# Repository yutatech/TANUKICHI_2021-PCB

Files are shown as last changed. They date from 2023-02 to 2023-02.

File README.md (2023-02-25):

# TANUKICHI_2021-PCB
This PCB is developed for RoboCup Junior Soccer. The robot has competed as "CAIO Tezukayama" in 2019 and "Leopard" in 2021.

## Related Web sites
- [Yuta's Blog](http://yuta.techblog.jp)
- [ Yuta - YouTube Channel](https://www.youtube.com/@yuta9428)
- [ Yuta@ciao_yuta - Twitter](https://twitter.com/ciao_yuta)

## Related Repositories
- [yutatech/RoboCup2021](https://github.com/yutatech/RoboCup2021)
- [yutatech/TANUKICHI_2021-Software](https://github.com/yutatech/TANUKICHI_2021-Software)

## Related Resources
#### TDP
- [Leopard RoboCup 2021 Team Discription Paper](http://yuta.techblog.jp/RoboCupJapanTournament2021/Leopard%20RoboCup%202021%20Team%20Discription%20Paper.pdf)

#### Video
- [Video - Leopard (Soccer Open) - RoboCup 2021 WORLDWIDE](https://www.youtube.com/watch?v=Lgoi_pQrCUY)
	- [This video](https://www.youtube.com/watch?v=PFkYVE7N84A) and [this video](https://www.youtube.com/watch?v=1l03lD6fXiQ) are also the same. Uploaded from TokyoTech.

## Awards
- ロボカップジュニア日本大会2021オンライン (RoboCup Junior Japan Tournament 2021 Online)
	- サッカーオープン 優勝 (SoccerOpen 1st Place)
	- ベストプレゼンビデオ賞 (Best Presentation Video Award)
	- ベストインタビュー賞 (Best Interview Award)
	- ベストビジュアルポスター賞 (Best Visual Poster Award)
- RoboCup 2021 WORLDWIDE
	- SoccerOpen Indvidual 1st Place
	- SoccerOpen SuperTeam 1st Place

## Environment
These files are edited with KiCAD 5.1.5

## PCB design files
- MAIN
	- This PCB is the main board of the robot. 
- MOTOR
	- This PCB drives 4 motors and 2 kickers. It is connected to MAIN with pin headers.
- LINE
	- This PCB includes 2 types of line sensor boards. The robot has two sensor boards of each type.
- TOP
	- This PCB distributes the wiring from MAIN to the devices mounted on top of the robot.
- BOTTOM
	- This PCB is connected to the line sensor board without using cables.
- BOOST V1
	- This PCB is a boost circuit for kickers. It outputs 60V. This version is installed to the robot because it is stable and works well.
- BOOST V2
	- This PCB is also a boost circuit for kickers. It outputs 150V. This version is an improvement on V1, but was not adopted because it would have caused noise in the surrounding circuit.
- ENCODER
	- This PCB is a magnetic pulse encoder board.
- PROTECTION
	- This PCB is Li-PO Battery protection circuit. The voltage of each cell is not monitored, so any imitation should be done at your own risk.

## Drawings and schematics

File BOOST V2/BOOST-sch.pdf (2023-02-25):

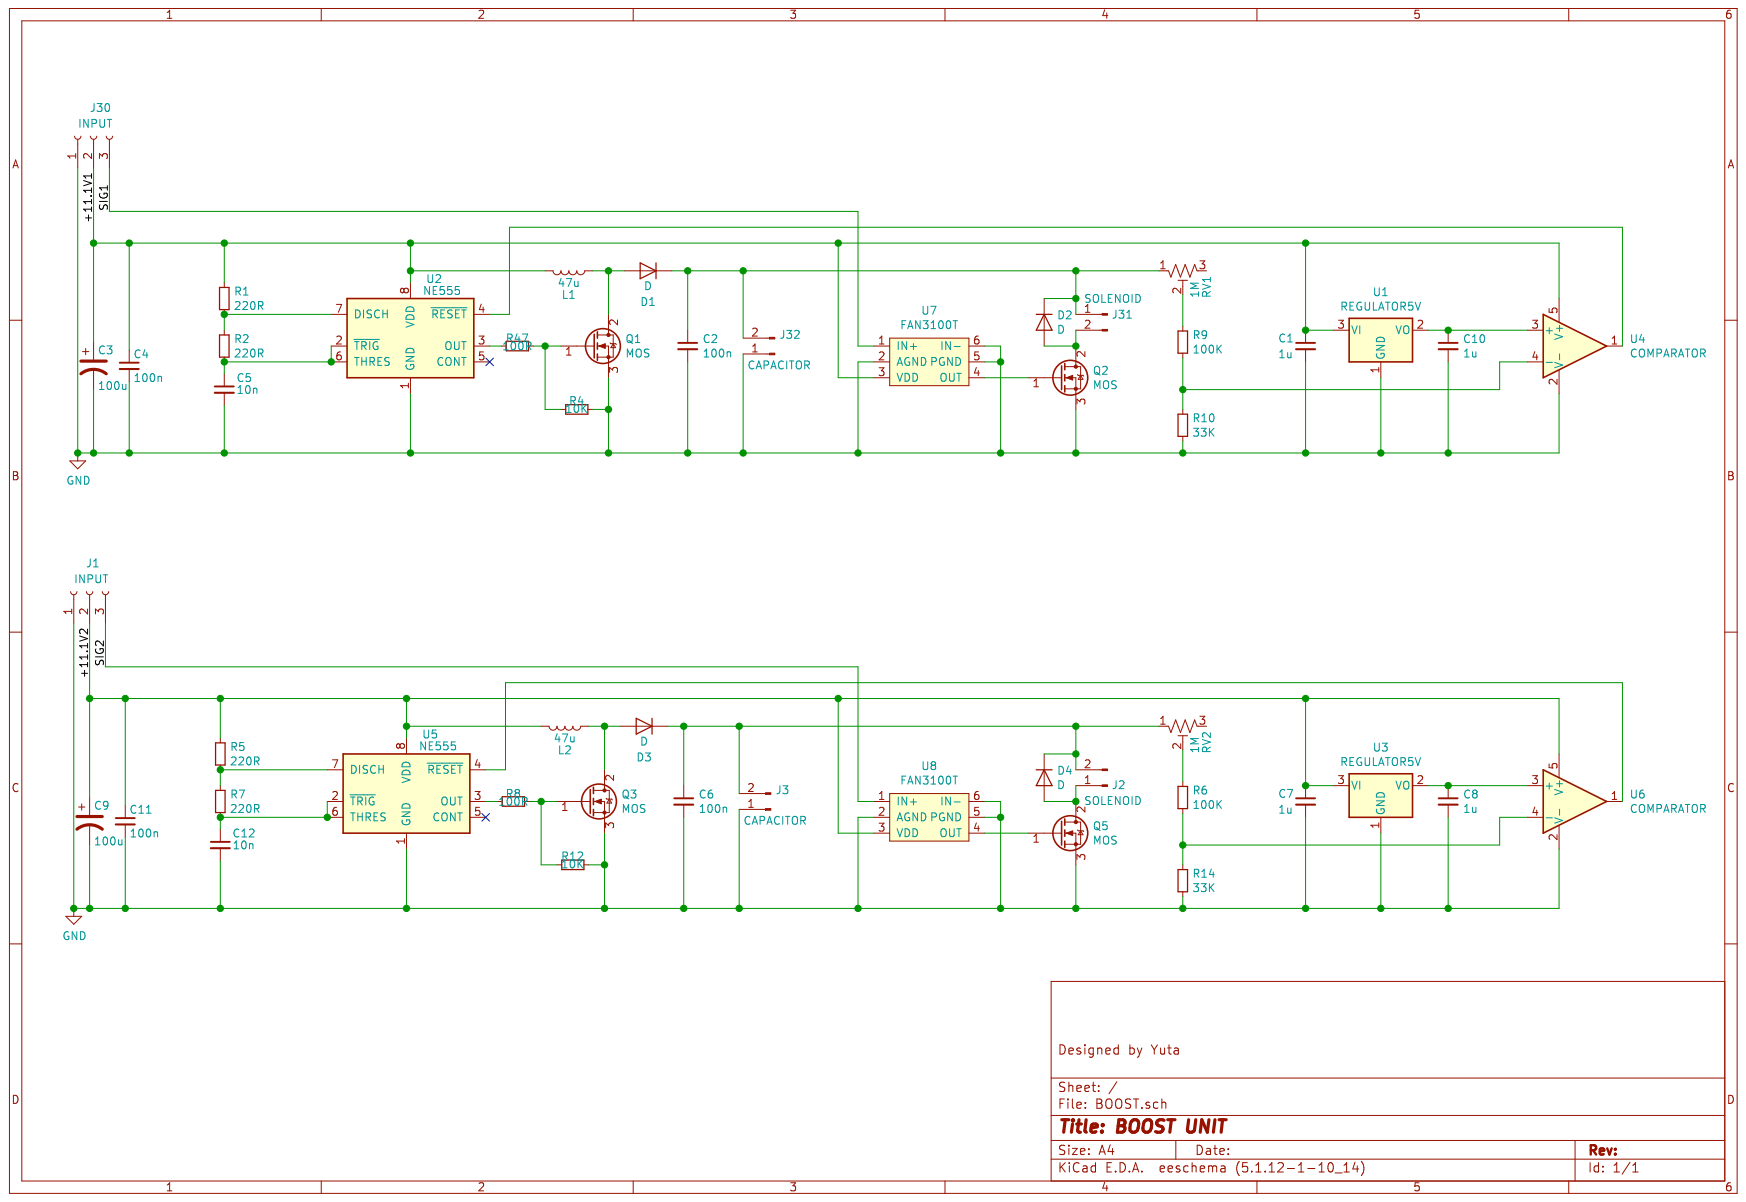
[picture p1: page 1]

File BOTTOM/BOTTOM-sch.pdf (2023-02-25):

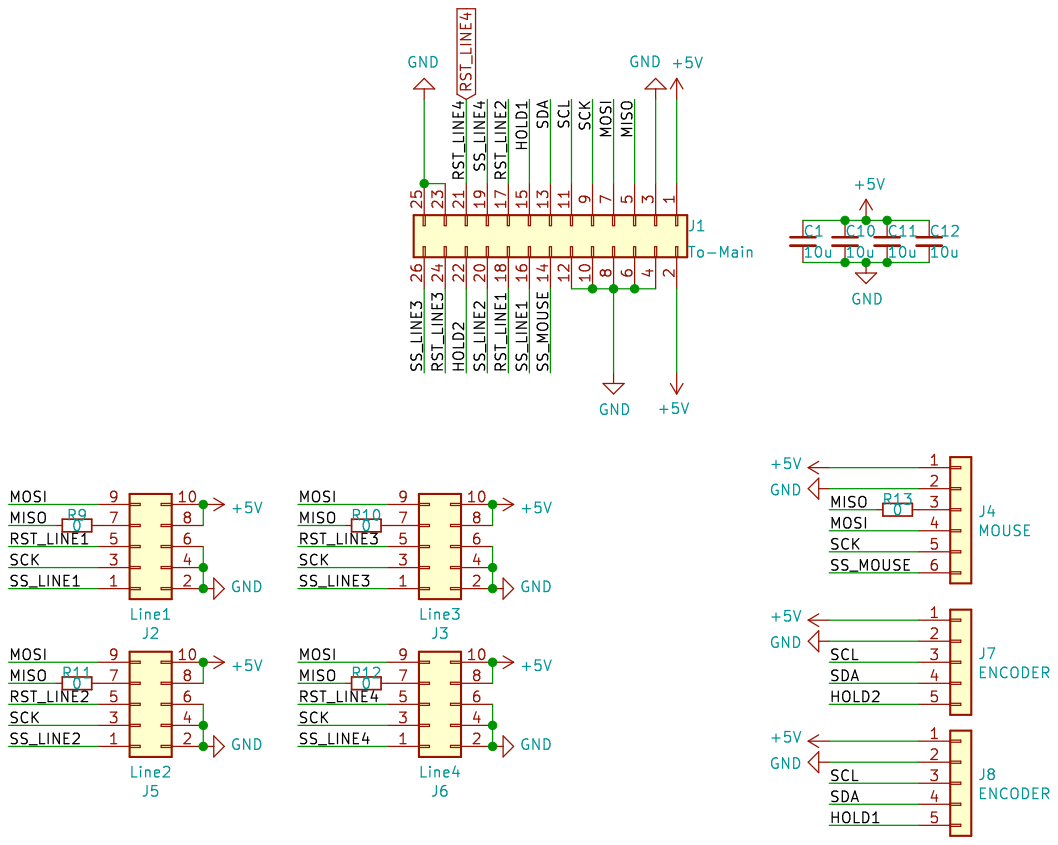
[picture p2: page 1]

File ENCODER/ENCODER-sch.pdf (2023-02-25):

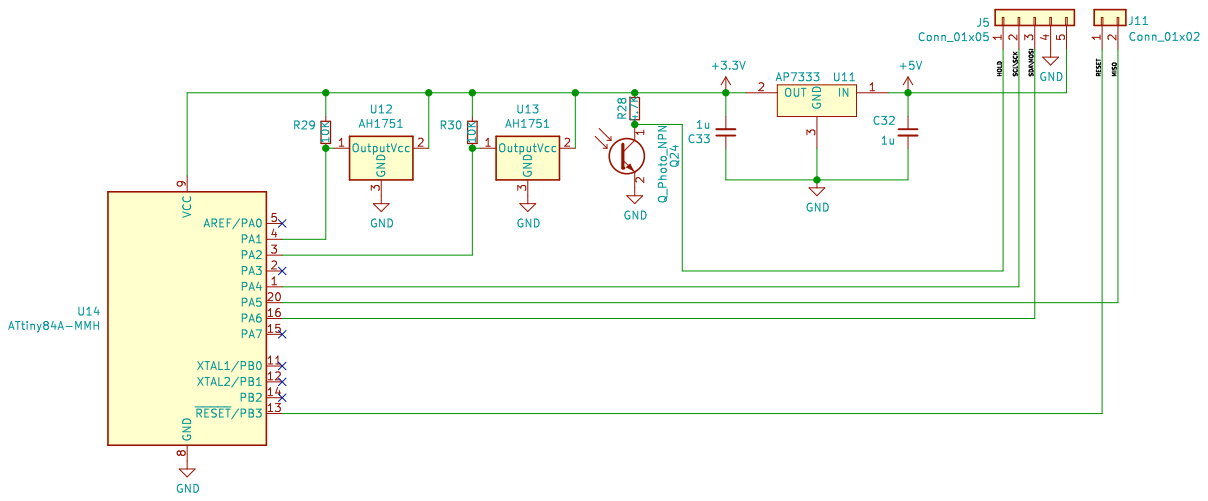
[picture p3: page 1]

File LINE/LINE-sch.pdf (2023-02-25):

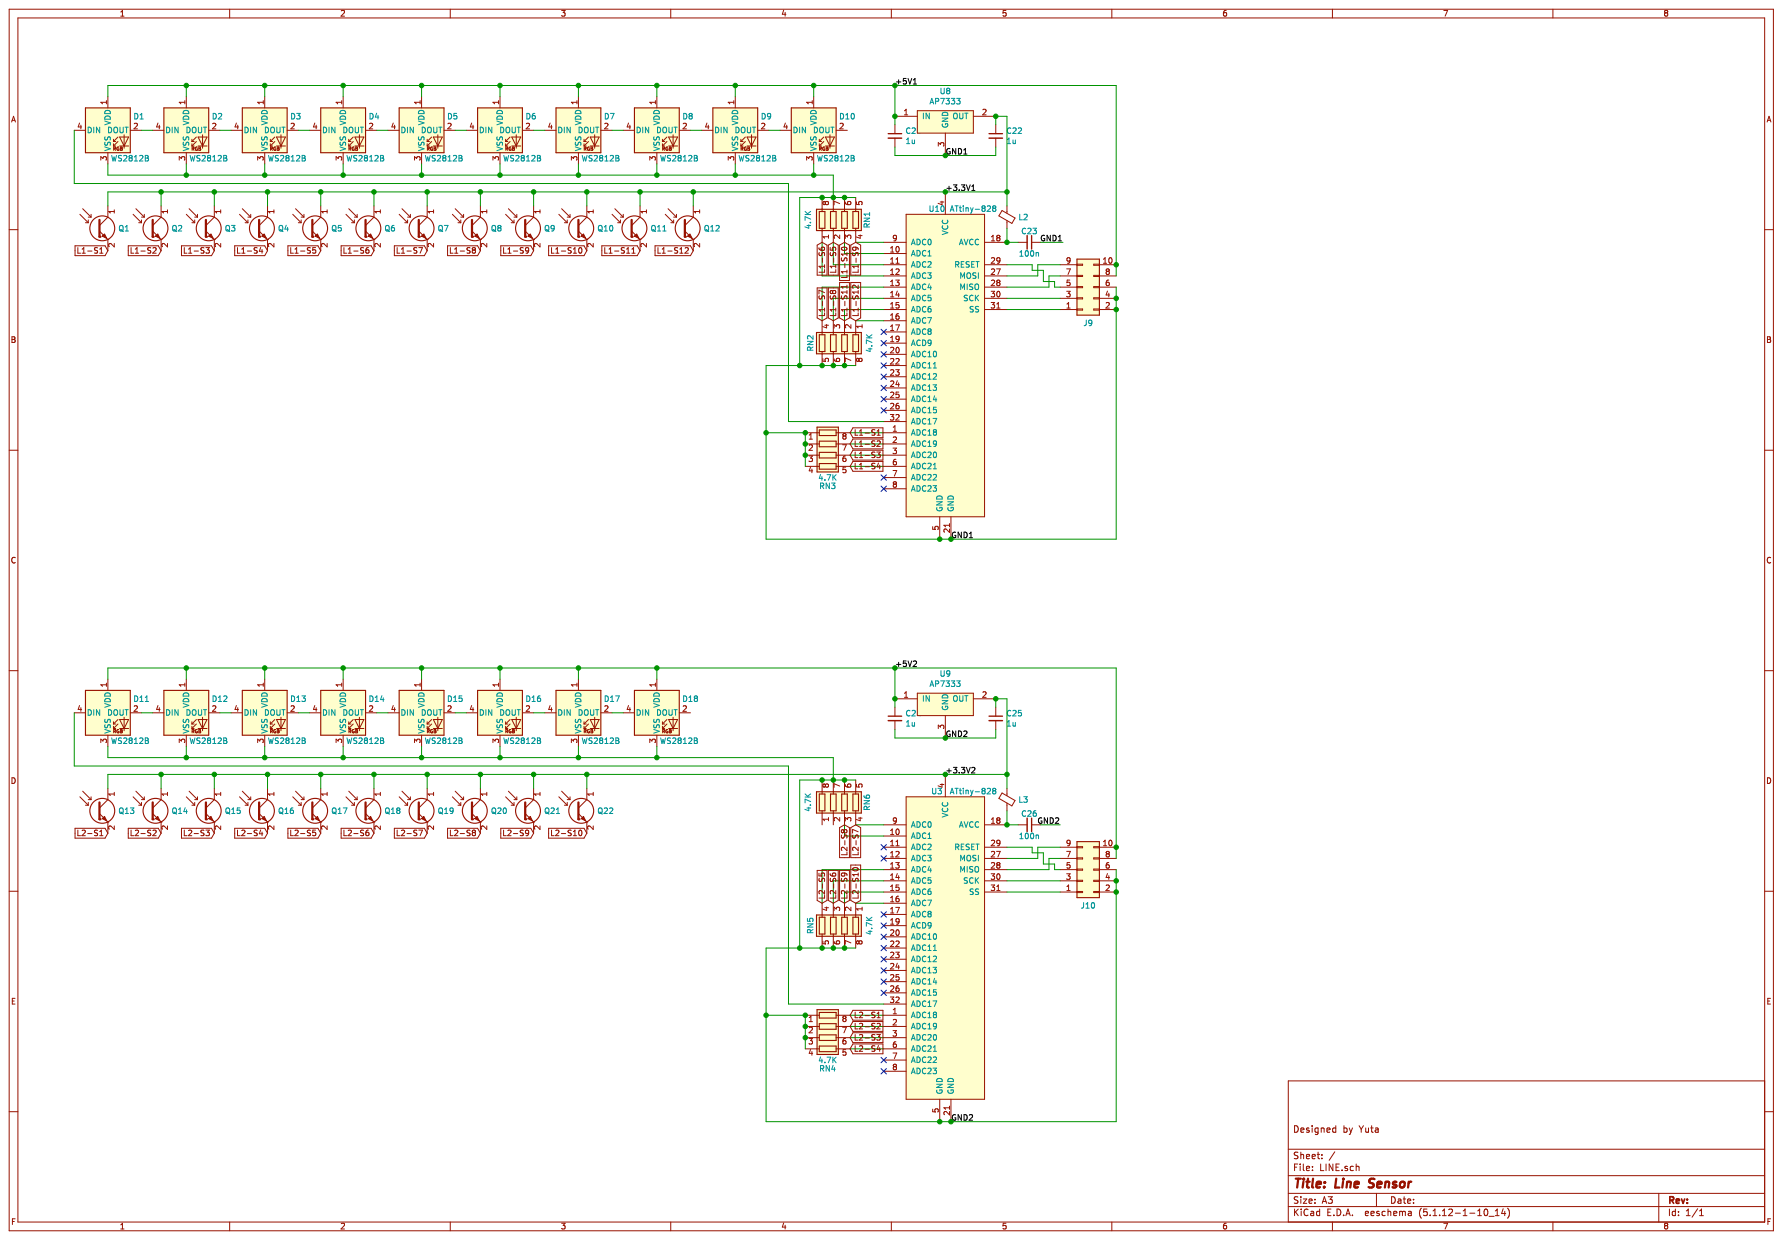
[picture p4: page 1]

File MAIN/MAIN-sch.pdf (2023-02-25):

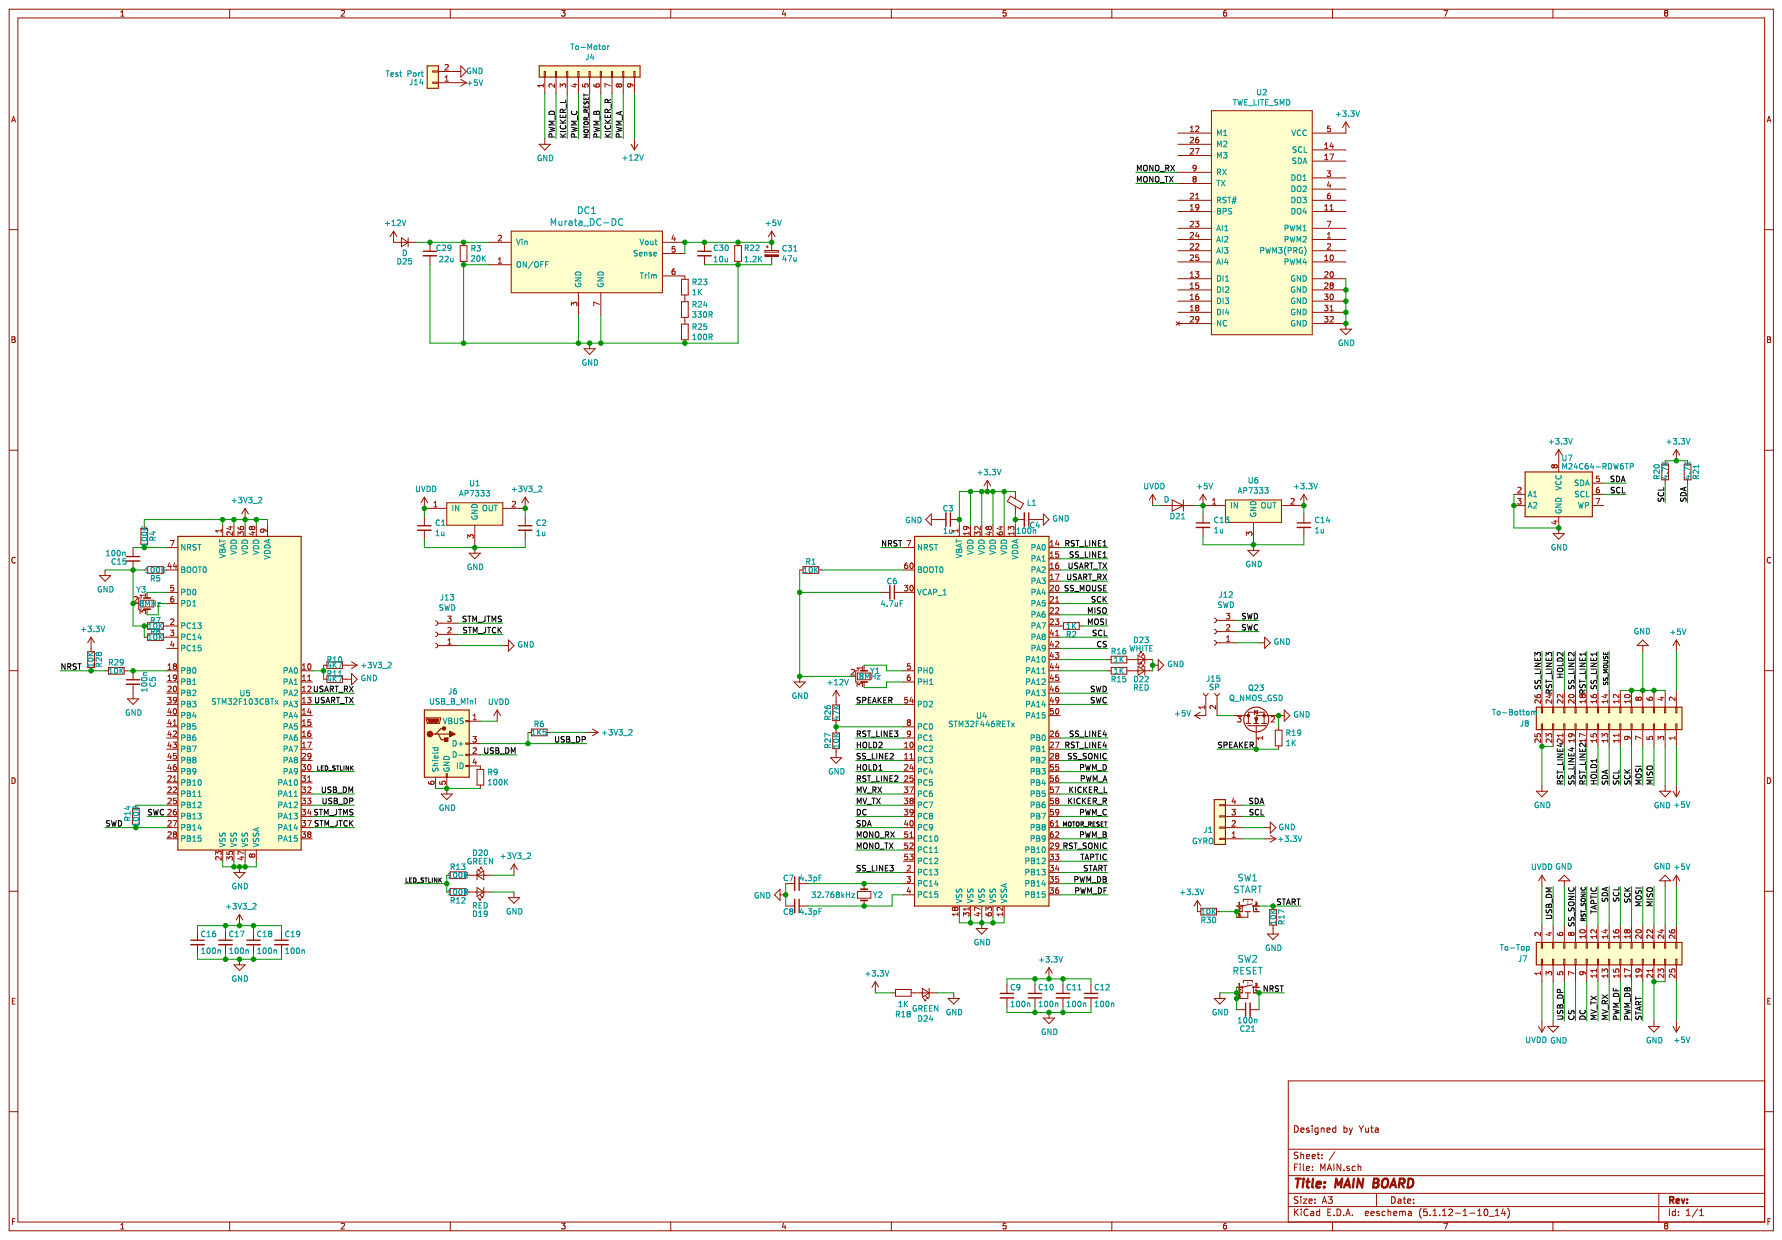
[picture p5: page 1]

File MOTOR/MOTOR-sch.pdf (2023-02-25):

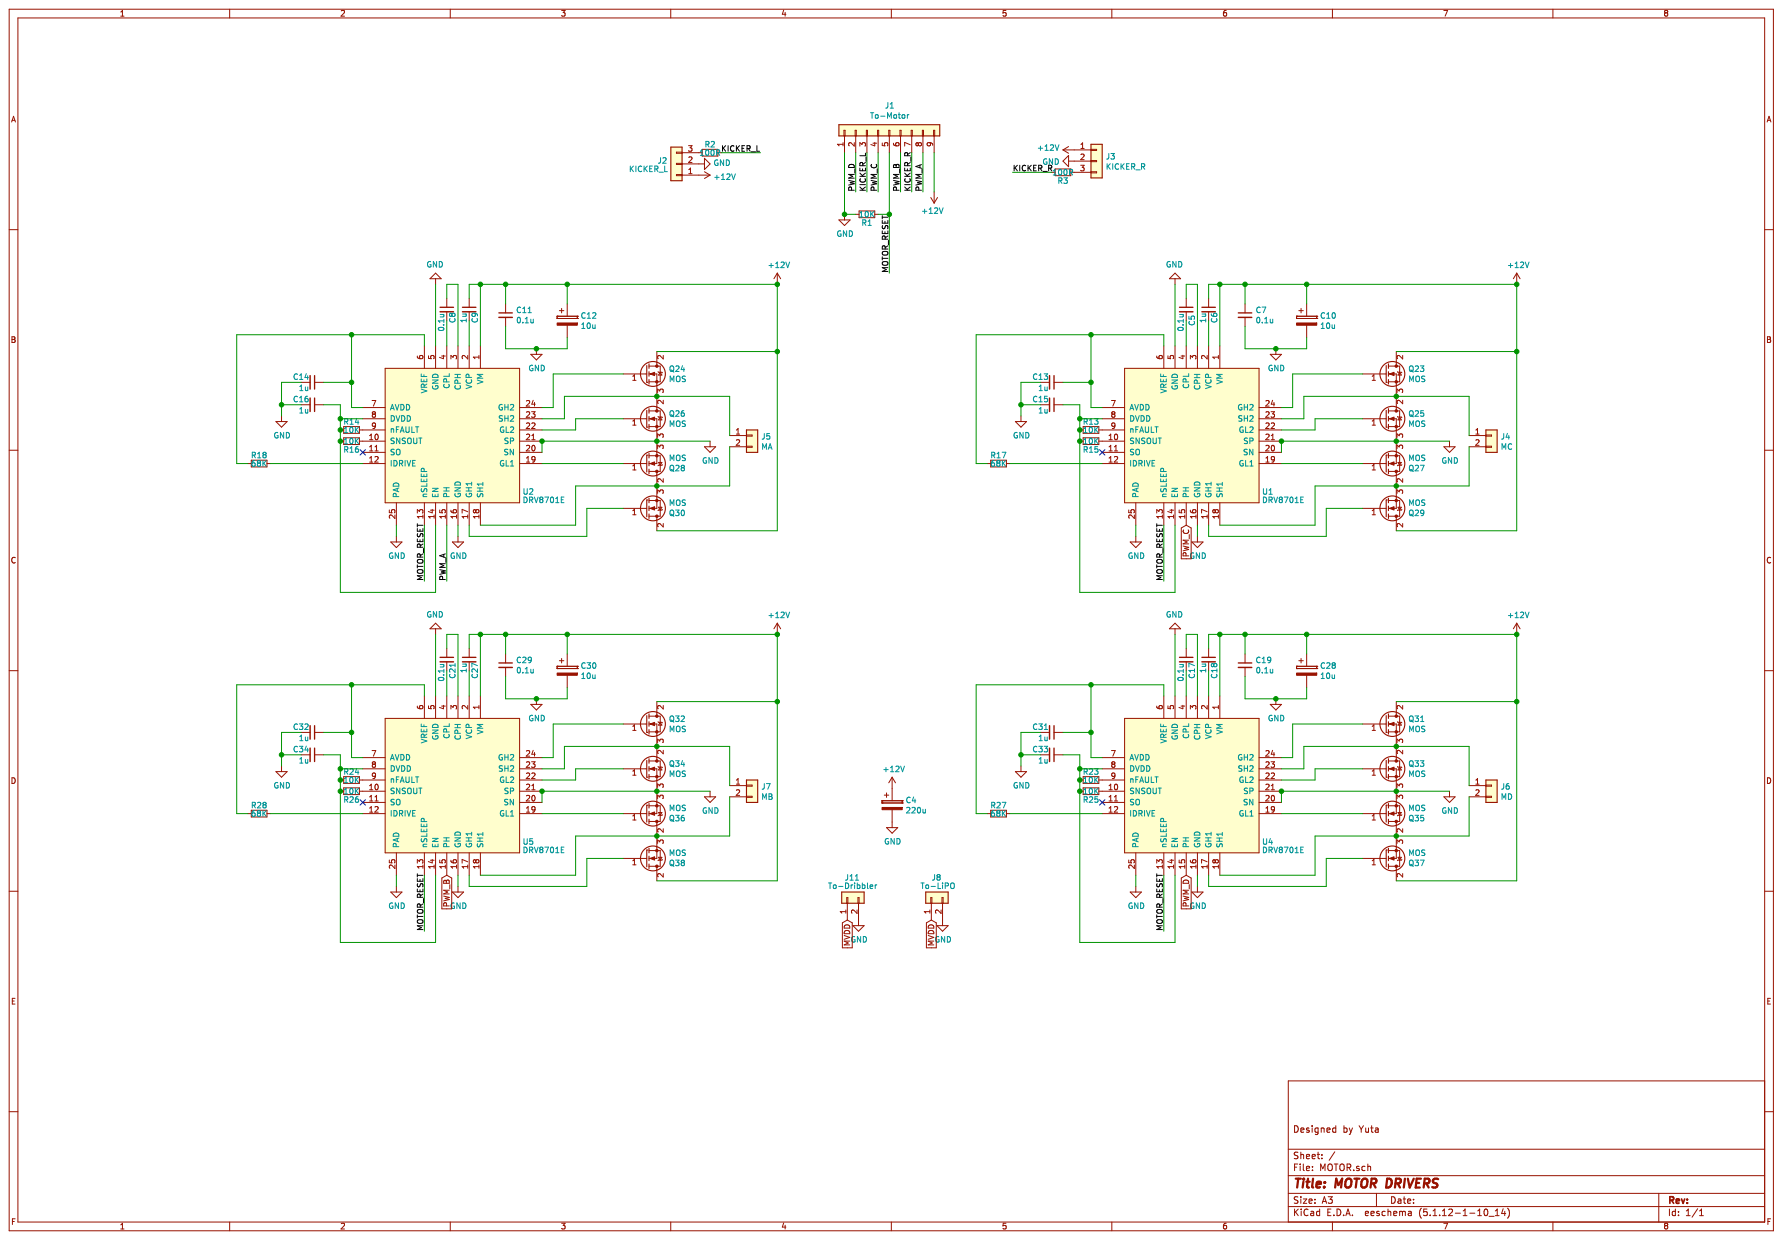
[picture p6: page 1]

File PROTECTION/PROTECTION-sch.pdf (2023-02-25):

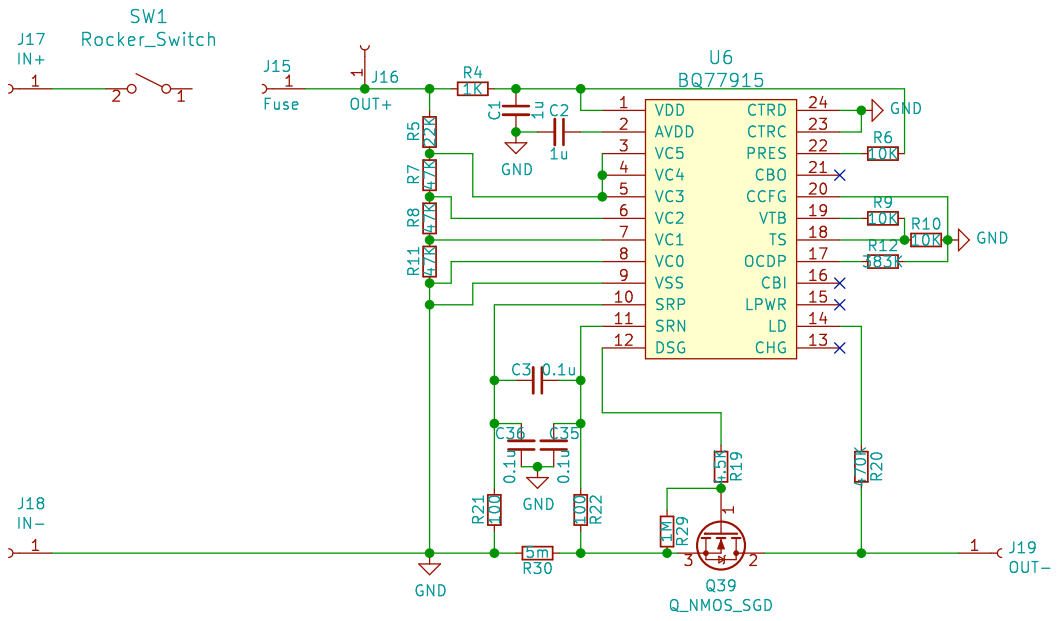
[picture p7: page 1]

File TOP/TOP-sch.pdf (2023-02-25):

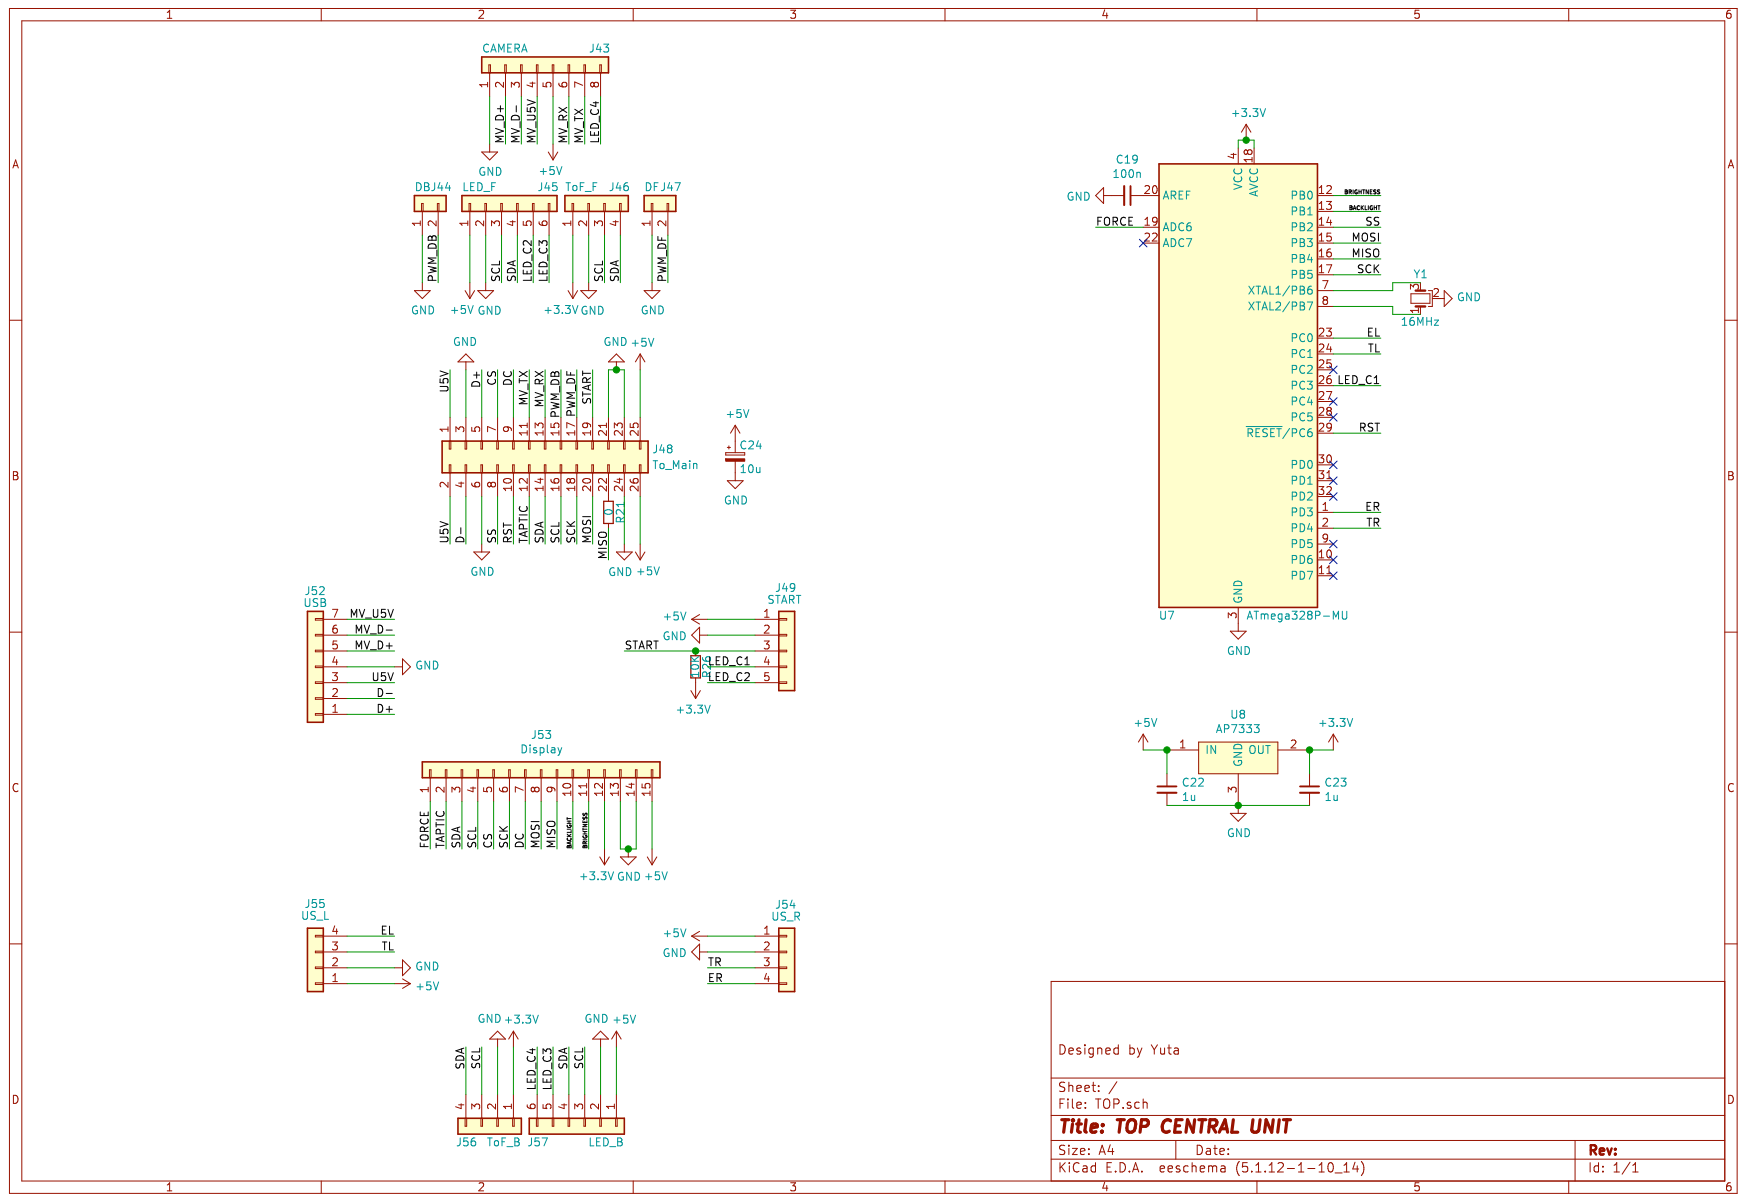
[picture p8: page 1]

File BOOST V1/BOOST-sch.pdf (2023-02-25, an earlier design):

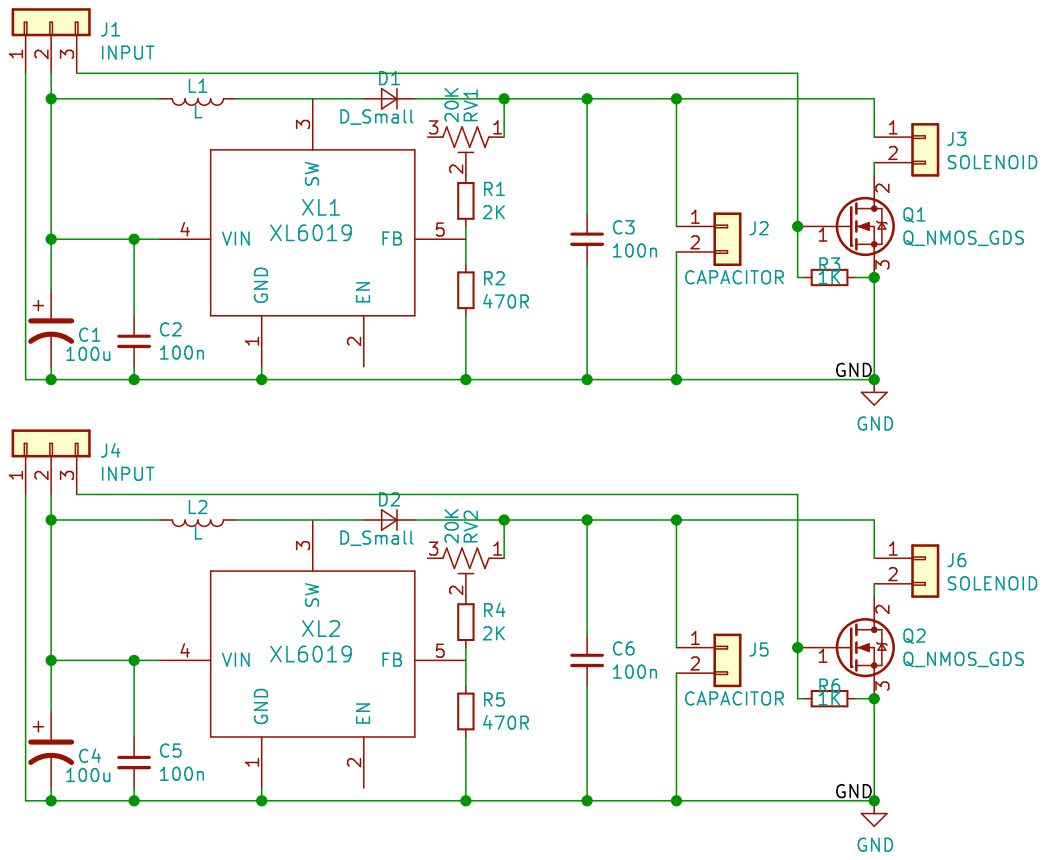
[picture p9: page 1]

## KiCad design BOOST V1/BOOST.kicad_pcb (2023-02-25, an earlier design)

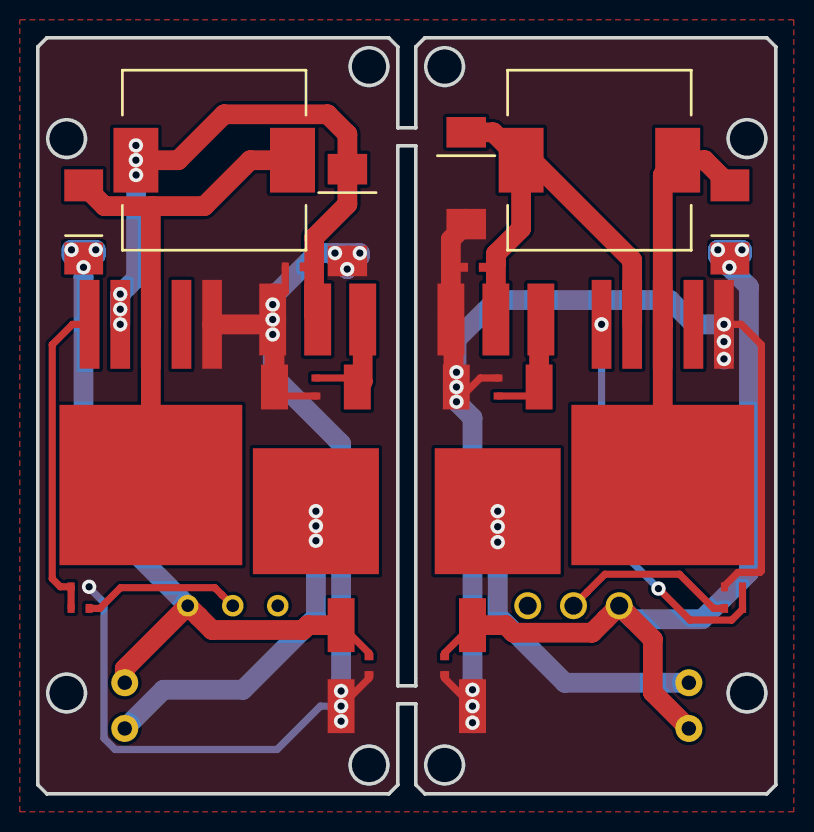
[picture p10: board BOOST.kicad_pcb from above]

Board: 2 copper layers, 41.0 x 42.0 mm, 28 parts (0 on the bottom side), 15 nets.

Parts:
C1, C4: 100u; TANTALCAP-6032
C2, C3, C5, C6: 100n; 1005
D1, D2: D_Small; DO-214AC
J1, J4: INPUT; 3Pads
J2, J5: CAPACITOR; 2Pads
J3, J6: SOLENOID; Molex_2pin_angled
L1, L2: L; Inductor_10x10x3.8
Q1, Q2: Q_NMOS_GDS; TO-252
R1, R4: 2K; 1005
R2, R5: 470R; 1005
R3, R6: 1K; 1005
RV1, RV2: 20K; CONN_01x03
XL1, XL2: XL6019; TO263-5L

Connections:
GND: C1.2, C2.2, C3.2, C4.2, C5.2, C6.2, J1.1, J2.2, J4.1, J5.2, Q1.3, Q2.3, R2.2, R3.1, R5.2, R6.1, XL1.1, XL2.1
unnamed: C1.1, C2.1, J1.2, L1.2, XL1.4
unnamed: C3.1, D1.1, J2.1, J3.1, RV1.1
unnamed: C4.1, C5.1, J4.2, L2.2, XL2.4
unnamed: C6.1, D2.1, J5.1, J6.1, RV2.1
unnamed: D1.2, L1.1, XL1.3
unnamed: D2.2, L2.1, XL2.3
unnamed: J1.3, Q1.1, R3.2
unnamed: J3.2, Q1.2
unnamed: J4.3, Q2.1, R6.2
unnamed: J6.2, Q2.2
unnamed: R1.1, RV1.2
unnamed: R1.2, R2.1, XL1.5
unnamed: R4.1, RV2.2
unnamed: R4.2, R5.1, XL2.5

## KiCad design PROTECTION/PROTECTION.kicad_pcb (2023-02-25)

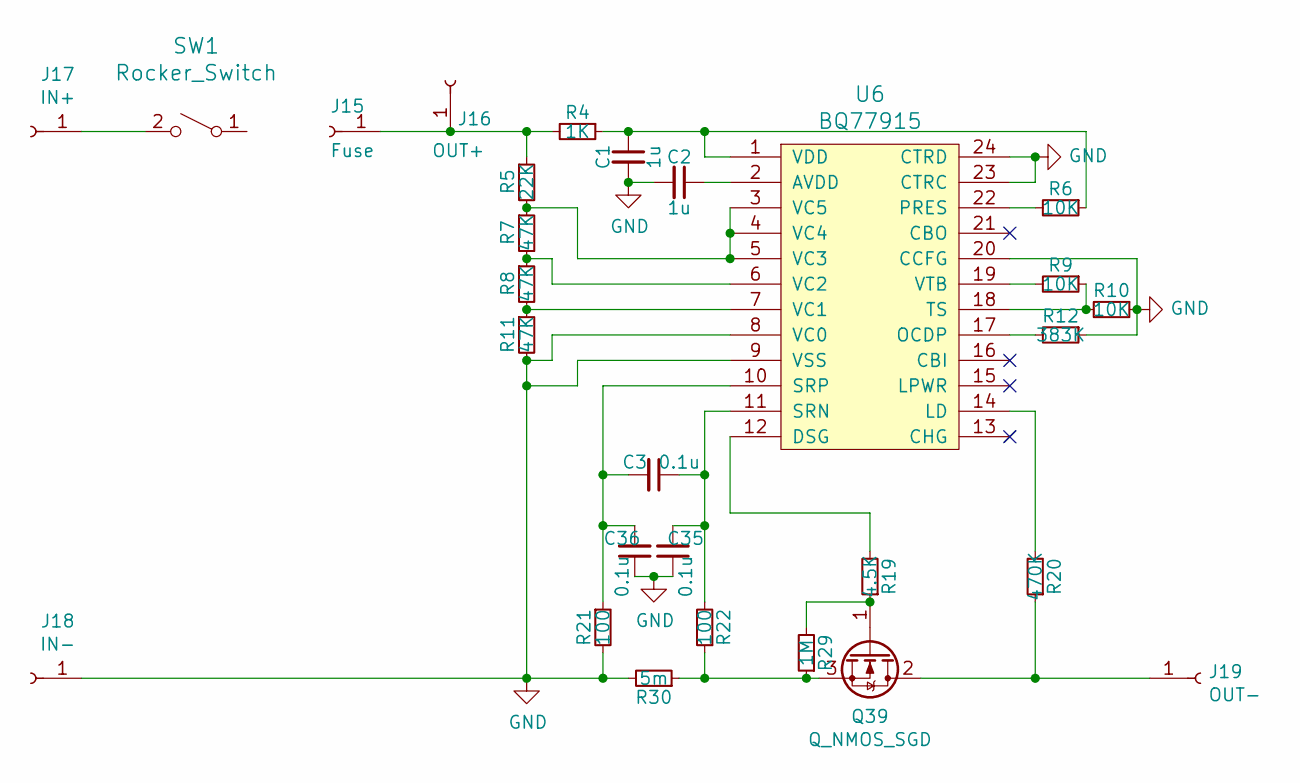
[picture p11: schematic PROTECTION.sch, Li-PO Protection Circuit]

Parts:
C1, C2: 1u; 1005
C3, C35, C36: 0.1u; 1005
J15: Fuse; 1PIN
J16: OUT+; 1PIN
J17: IN+; 1PIN
J18: IN-; 1PIN
J19: OUT-; 1PIN
Q39: Q_NMOS_SGD; TO-252; Part # DMTH6005LK3-13
R4: 1K; 1005
R5: 22K; 1005
R6, R9, R10: 10K; 1005
R7, R8, R11: 47K; 1005
R12: 383K; 1005
R19: 4.5K; 1005
R20: 470K; 1005
R21, R22: 100; 1005
R29: 1M; 1005
R30: 5m; 6432; Part # PCS2512FR0050ET
SW1: Rocker_Switch; 2Pads; Part # DS-850K-S-LG-K
U6: BQ77915; TSSOP-24

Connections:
GND: C1.2, C2.2, C35.1, C36.1, J18.1, R10.1, R11.2, R12.1, R21.2, R30.2, U6.8 (VC0), U6.9 (VSS), U6.20 (CCFG), U6.23 (CTRC), U6.24 (CTRD)
unnamed: C1.1, R4.1, R6.1, U6.1 (VDD)
unnamed: C2.1, U6.2 (AVDD)
unnamed: C3.1, C35.2, R22.2, U6.11 (SRN)
unnamed: C3.2, C36.2, R21.1, U6.10 (SRP)
unnamed: J15.1, J16.1, R4.2, R5.1
unnamed: J17.1, SW1.2 (B)
unnamed: J19.1, Q39.2 (D), R20.1
unnamed: Q39.1 (G), R19.1, R29.2
unnamed: Q39.3 (S), R22.1, R29.1, R30.1
unnamed: R5.2, R7.1, U6.3 (VC5), U6.4 (VC4), U6.5 (VC3)
unnamed: R6.2, U6.22 (PRES)
unnamed: R7.2, R8.1, U6.6 (VC2)
unnamed: R9.2, U6.19 (VTB)
unnamed: R9.1, R10.2, U6.18 (TS)
unnamed: R8.2, R11.1, U6.7 (VC1)
unnamed: R12.2, U6.17 (OCDP)
unnamed: R19.2, U6.12 (DSG)
unnamed: R20.2, U6.14 (LD)

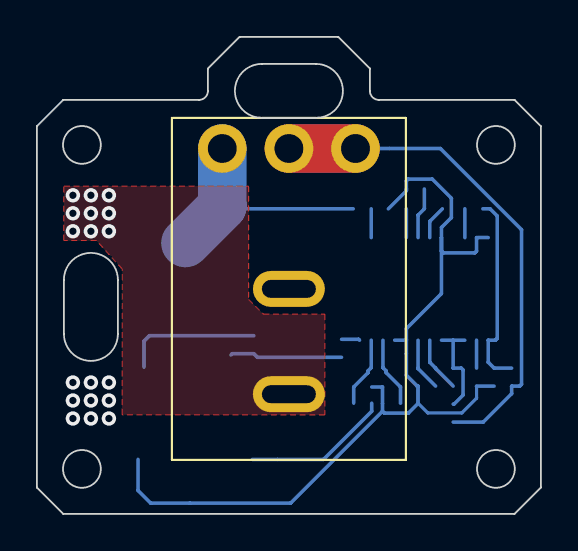
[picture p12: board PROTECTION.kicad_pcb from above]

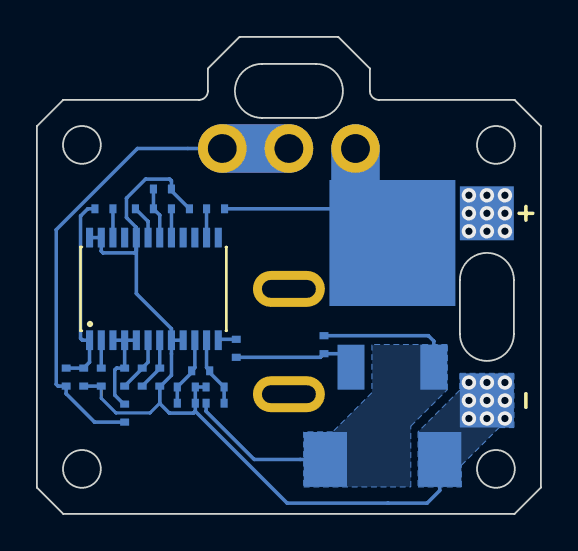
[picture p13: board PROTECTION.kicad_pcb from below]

Board: 2 copper layers, 28.0 x 26.5 mm, 28 parts (24 on the bottom side), 19 nets.

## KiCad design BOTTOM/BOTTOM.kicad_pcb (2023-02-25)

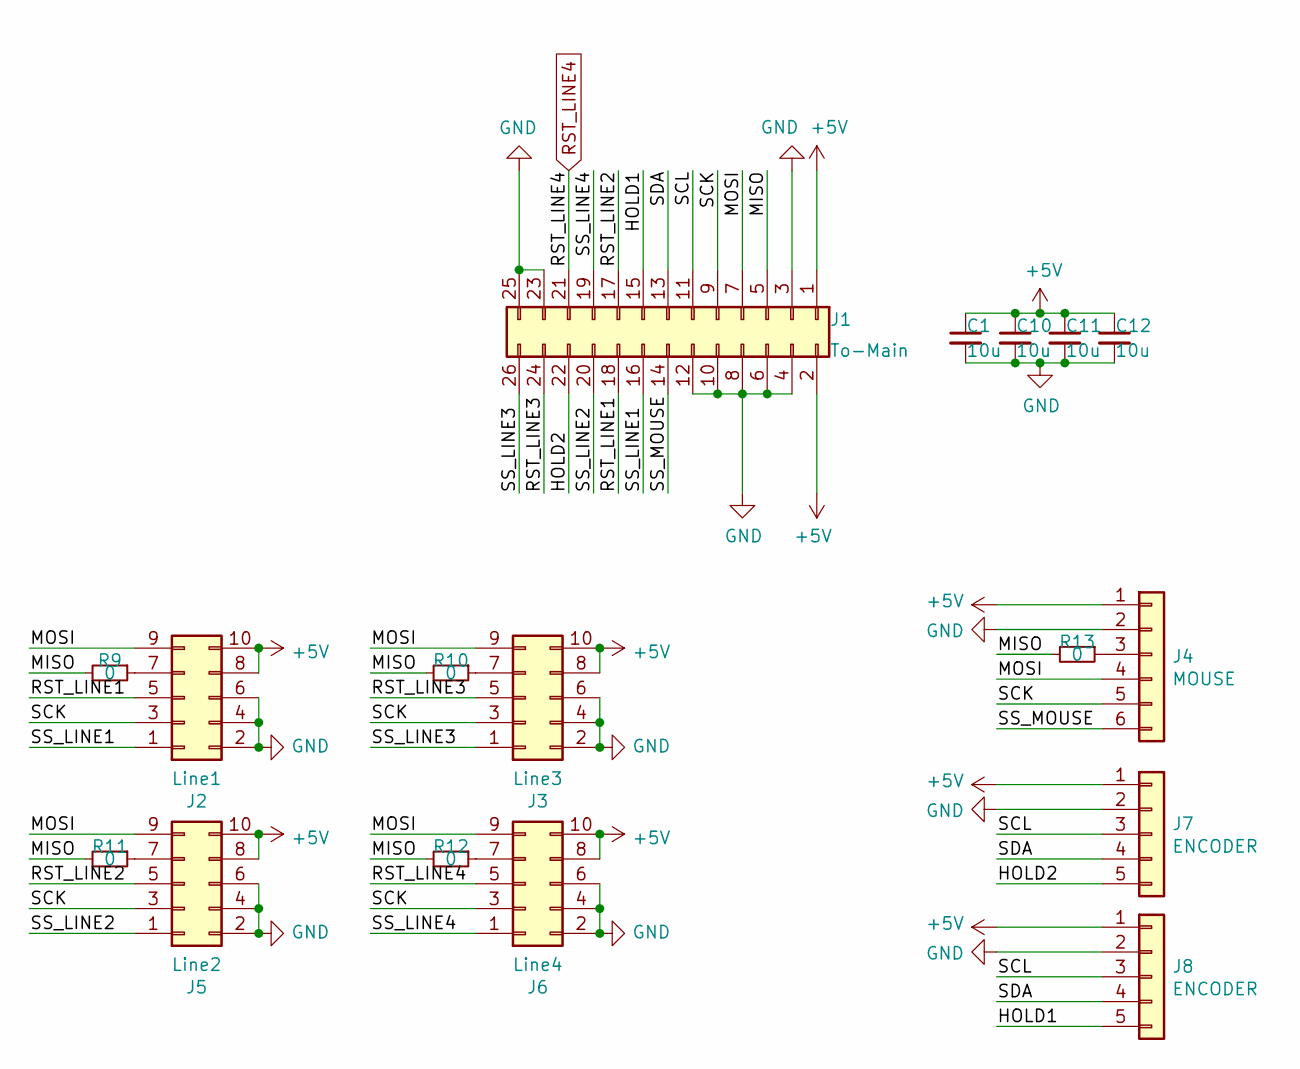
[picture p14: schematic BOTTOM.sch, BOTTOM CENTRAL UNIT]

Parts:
C1, C10, C11, C12: 10u; 2012
J1: To-Main; IDC_Header_Straight_26pins_P1.27mm; Part # 3220-26-0100-00
J2: Line1; CONN_SPRING_02x05_PADS
J3: Line3; CONN_SPRING_02x05_PADS
J4: MOUSE; CONN_01x06
J5: Line2; CONN_SPRING_02x05_PADS
J6: Line4; CONN_SPRING_02x05_PADS
J7, J8: ENCODER; CONN_01x05
R9, R10, R11, R12, R13: 0; 1005

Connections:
+5V: C1.1, C10.1, C11.1, C12.1, J1.1, J1.2, J2.8, J2.10, J3.8, J3.10, J4.1, J5.8, J5.10, J6.8, J6.10, J7.1, J8.1
/HOLD1: J1.15, J8.5
/HOLD2: J1.22, J7.5
/MISO: J1.5, R9.2, R10.2, R11.2, R12.2, R13.2
/MOSI: J1.7, J2.9, J3.9, J4.4, J5.9, J6.9
/RST_LINE1: J1.18, J2.5
/RST_LINE2: J1.17, J5.5
/RST_LINE3: J1.24, J3.5
/SCK: J1.9, J2.3, J3.3, J4.5, J5.3, J6.3
/SCL: J1.11, J7.3, J8.3
/SDA: J1.13, J7.4, J8.4
/SS_LINE1: J1.16, J2.1
/SS_LINE2: J1.20, J5.1
/SS_LINE3: J1.26, J3.1
/SS_LINE4: J1.19, J6.1
/SS_MOUSE: J1.14, J4.6
GND: C1.2, C10.2, C11.2, C12.2, J1.3, J1.4, J1.6, J1.8, J1.10, J1.12, J1.23, J1.25, J2.2, J2.4, J2.6, J3.2, J3.4, J3.6, J4.2, J5.2, J5.4, J5.6, J6.2, J6.4, J6.6, J7.2, J8.2
unnamed: J2.7, R9.1
unnamed: J3.7, R10.1
unnamed: J4.3, R13.1
unnamed: J5.7, R11.1
unnamed: J6.7, R12.1
RST_LINE4: J1.21, J6.5

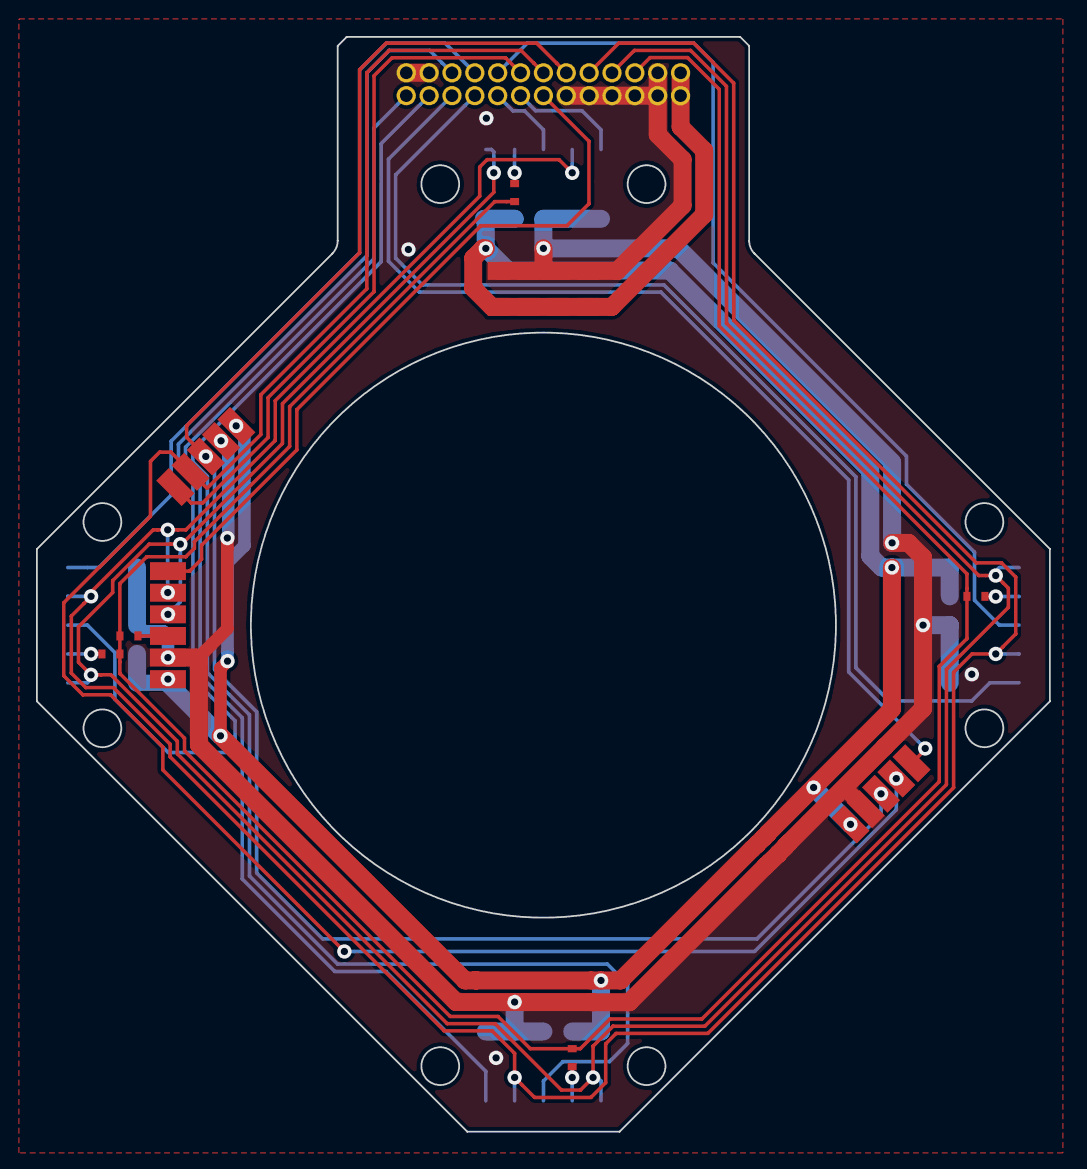
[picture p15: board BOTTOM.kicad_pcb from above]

Board: 2 copper layers, 56.3 x 60.8 mm, 17 parts (0 on the bottom side), 23 nets.

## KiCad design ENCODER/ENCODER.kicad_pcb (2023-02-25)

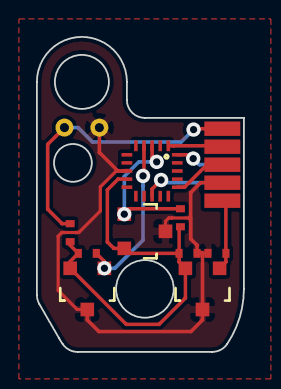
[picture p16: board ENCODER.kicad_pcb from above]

Board: 2 copper layers, 11.5 x 17.5 mm, 12 parts (1 on the bottom side), 10 nets.

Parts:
C32, C33: 1u; 1005
J5: Conn_01x05; CONN_01x05
J11: Conn_01x02; 2Pads
Q24: Q_Photo_NPN; 2Pads
R28: 4.7K; 1005
R29, R30: 10K; 1005
U11: AP7333; Q_SOT-23
U12, U13: AH1751; Q_SOT-23
U14: ATtiny84A-MMH; QFN-20_P0.45

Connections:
+3V3: C33.2, R28.2, R29.1, R30.1, U11.2, U12.2, U13.2, U14.9
+5V: C32.1, J5.5, U11.1
/HOLD: J5.1, Q24.1, R28.1
/MISO: J11.2, U14.20
/RESET: J11.1, U14.13
/SCL\SCK: J5.2, U14.1
/SDA\MOSI: J5.3, U14.16
GND: C32.2, C33.1, J5.4, Q24.2, U11.3, U12.3, U13.3, U14.8
unnamed: R29.2, U12.1, U14.4
unnamed: R30.2, U13.1, U14.3

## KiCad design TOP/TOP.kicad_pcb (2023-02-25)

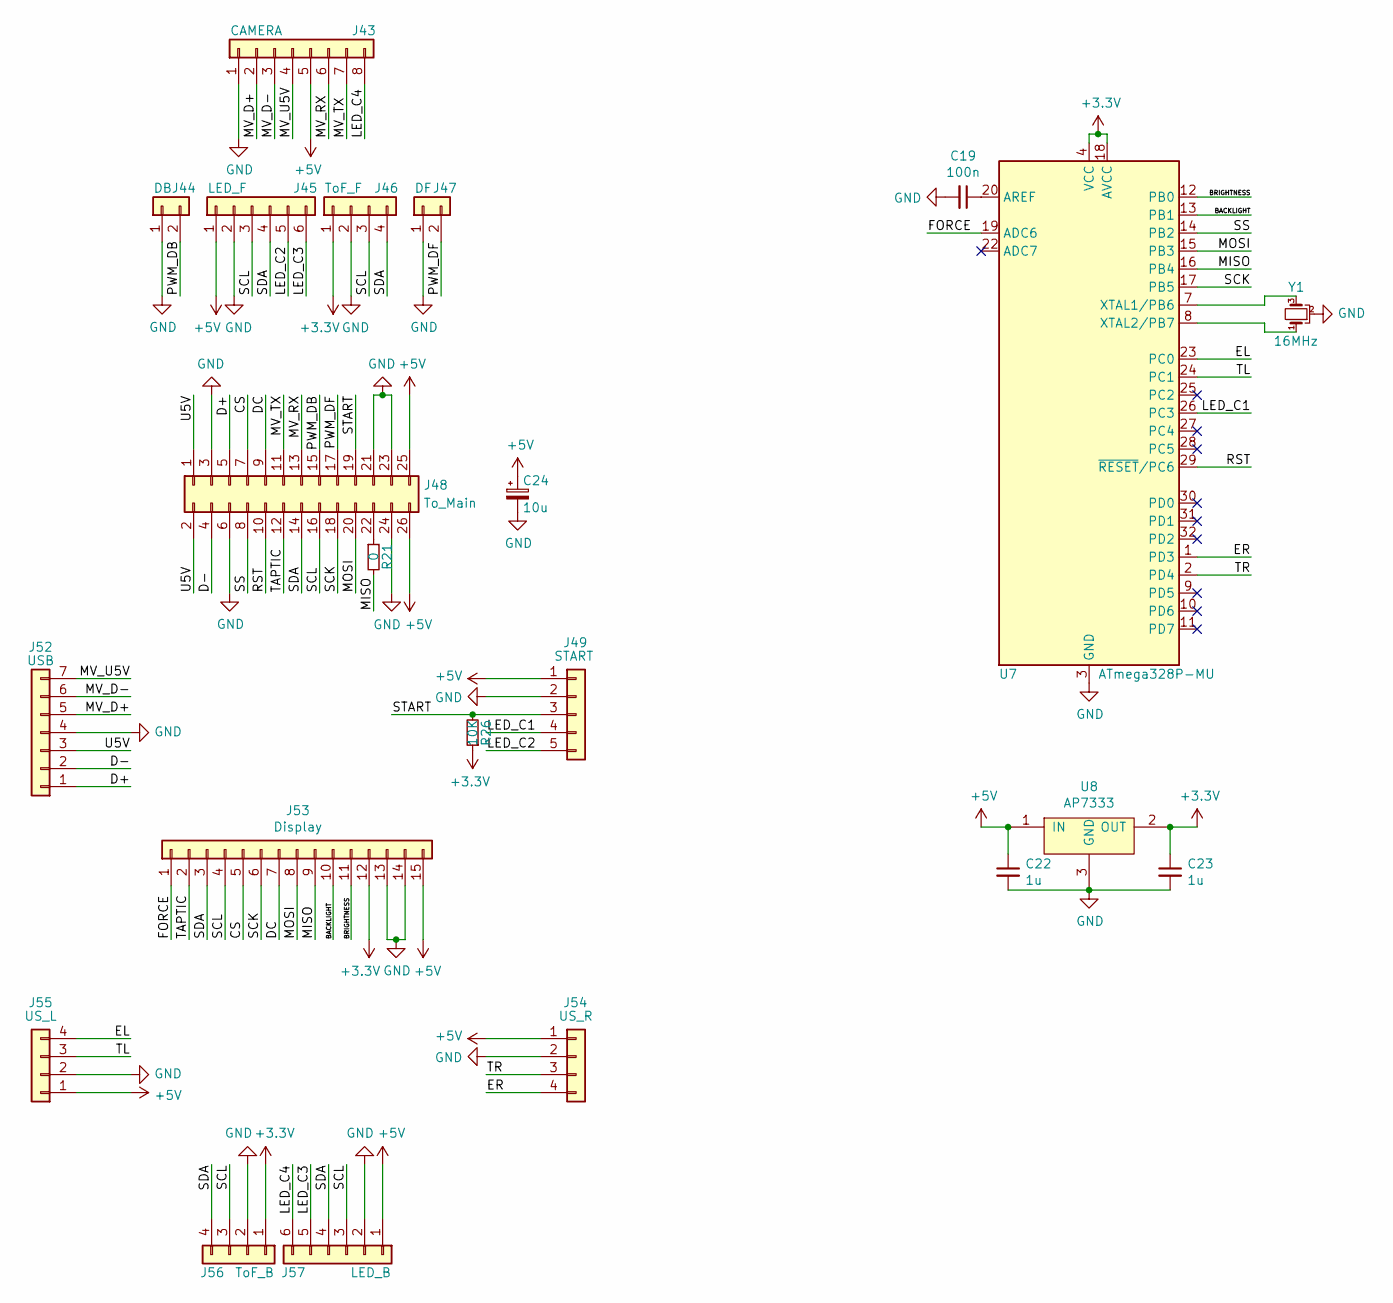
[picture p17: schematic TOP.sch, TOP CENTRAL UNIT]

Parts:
C19: 100n; 1005
C22, C23: 1u; 1005
C24: 10u; CAPACITOR_φ4
J43: CAMERA; PH-ST08
J44: DB; PH-ST02
J45: LED_F; PH-ST06
J46: ToF_F; PH-ST04
J47: DF; PH-ST02
J48: To_Main; IDC_Header_Straight_26pins_P1.27mm; Part # 3220-26-0100-00
J49: START; PH-ST05
J52: USB; PH-ST07
J53: Display; FFC 15P
J54: US_R; PH-ST04
J55: US_L; PH-ST04
J56: ToF_B; PH-ST04
J57: LED_B; PH-ST06
R21: 0; 1005
R26: 10K; 1005
U7: ATmega328P-MU; VQFN-32-5x5mm_P0.5mm
U8: AP7333; Q_SOT-23
Y1: 16MHz; CERALOCK; Part # CSTNE16M0V530000R0

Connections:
+3V3: C23.1, J46.1, J53.12, J56.1, R26.1, U7.4 (VCC), U7.6 (VCC), U7.18 (AVCC), U8.2 (OUT)
+5V: C22.1, C24.1, J43.5, J45.1, J48.25, J48.26, J49.1, J53.15, J54.1, J55.1, J57.1, U8.1 (IN)
/BACKLIGHT: J53.10, U7.13 (PB1)
/BRIGHTNESS: J53.11, U7.12 (PB0)
/CS: J48.7, J53.5
/D+: J48.5, J52.1
/D-: J48.4, J52.2
/DC: J48.9, J53.7
/EL: J55.4, U7.23 (PC0)
/ER: J54.4, U7.1 (PD3)
/FORCE: J53.1, U7.19 (ADC6)
/LED_C1: J49.4, U7.26 (PC3)
/LED_C2: J45.5, J49.5
/LED_C3: J45.6, J57.5
/LED_C4: J43.8, J57.6
/MISO: J53.9, R21.2, U7.16 (PB4)
/MOSI: J48.20, J53.8, U7.15 (PB3)
/MV_D+: J43.2, J52.5
/MV_D-: J43.3, J52.6
/MV_RX: J43.6, J48.13
/MV_TX: J43.7, J48.11
/MV_U5V: J43.4, J52.7
/PWM_DB: J44.2, J48.15
/PWM_DF: J47.2, J48.17
/RST: J48.10, U7.29 (~RESET~/PC6)
/SCK: J48.18, J53.6, U7.17 (PB5)
/SCL: J45.3, J46.3, J48.16, J53.4, J56.3, J57.3
/SDA: J45.4, J46.4, J48.14, J53.3, J56.4, J57.4
/SS: J48.8, U7.14 (PB2)
/START: J48.19, J49.3, R26.2
/TAPTIC: J48.12, J53.2
/TL: J55.3, U7.24 (PC1)
/TR: J54.3, U7.2 (PD4)
/U5V: J48.1, J48.2, J52.3
GND: C19.2, C22.2, C23.2, C24.2, J43.1, J44.1, J45.2, J46.2, J47.1, J48.3, J48.6, J48.21, J48.23, J48.24, J49.2, J52.4, J53.13, J53.14, J54.2, J55.2, J56.2, J57.2, U7.3 (GND), U7.5 (GND), U7.21 (GND), U7.33 (GND), U8.3 (GND), Y1.2
unnamed: C19.1, U7.20 (AREF)
unnamed: J48.22, R21.1
unnamed: U7.7 (XTAL1/PB6), Y1.3
unnamed: U7.8 (XTAL2/PB7), Y1.1

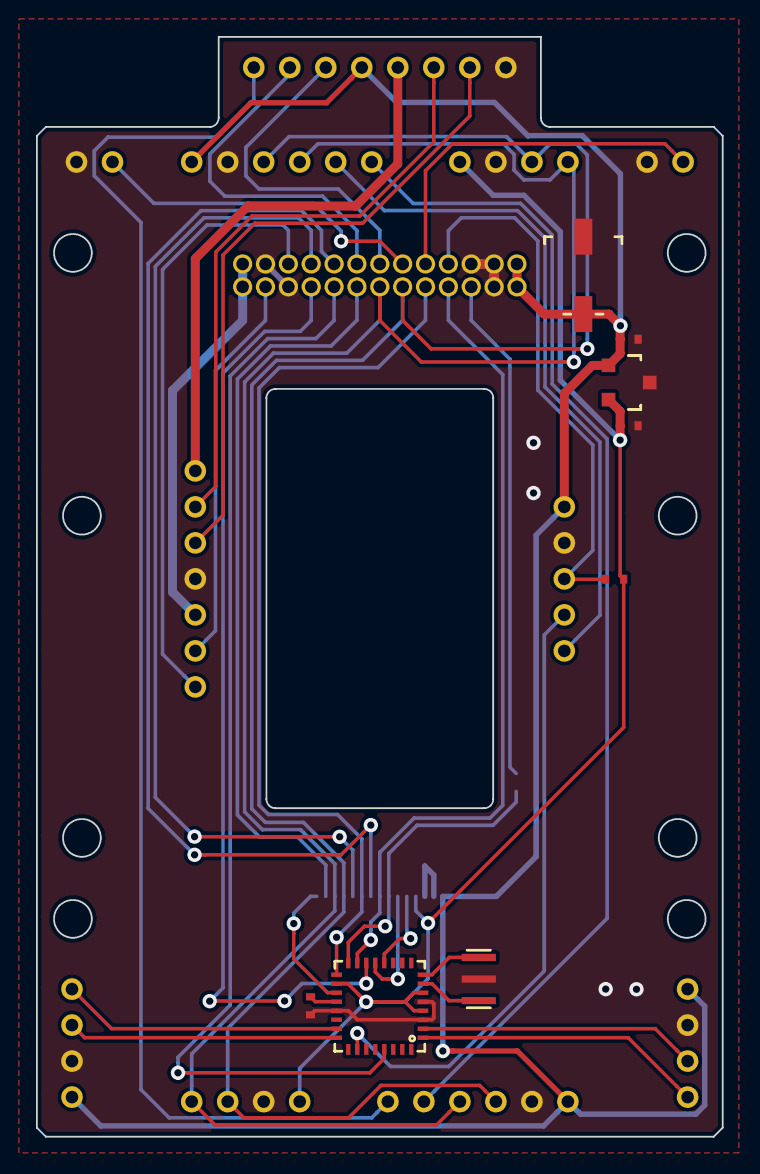
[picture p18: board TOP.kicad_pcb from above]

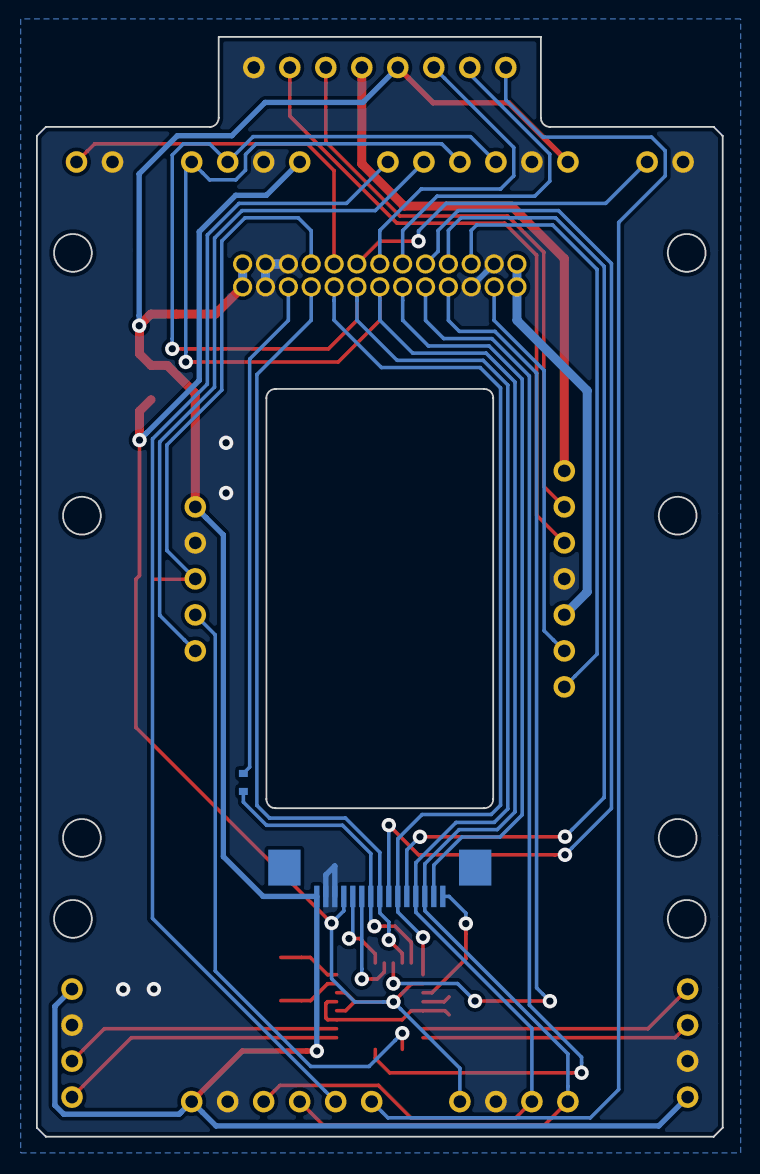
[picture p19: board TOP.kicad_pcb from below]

Board: 2 copper layers, 38.1 x 61.1 mm, 22 parts (13 on the bottom side), 39 nets.

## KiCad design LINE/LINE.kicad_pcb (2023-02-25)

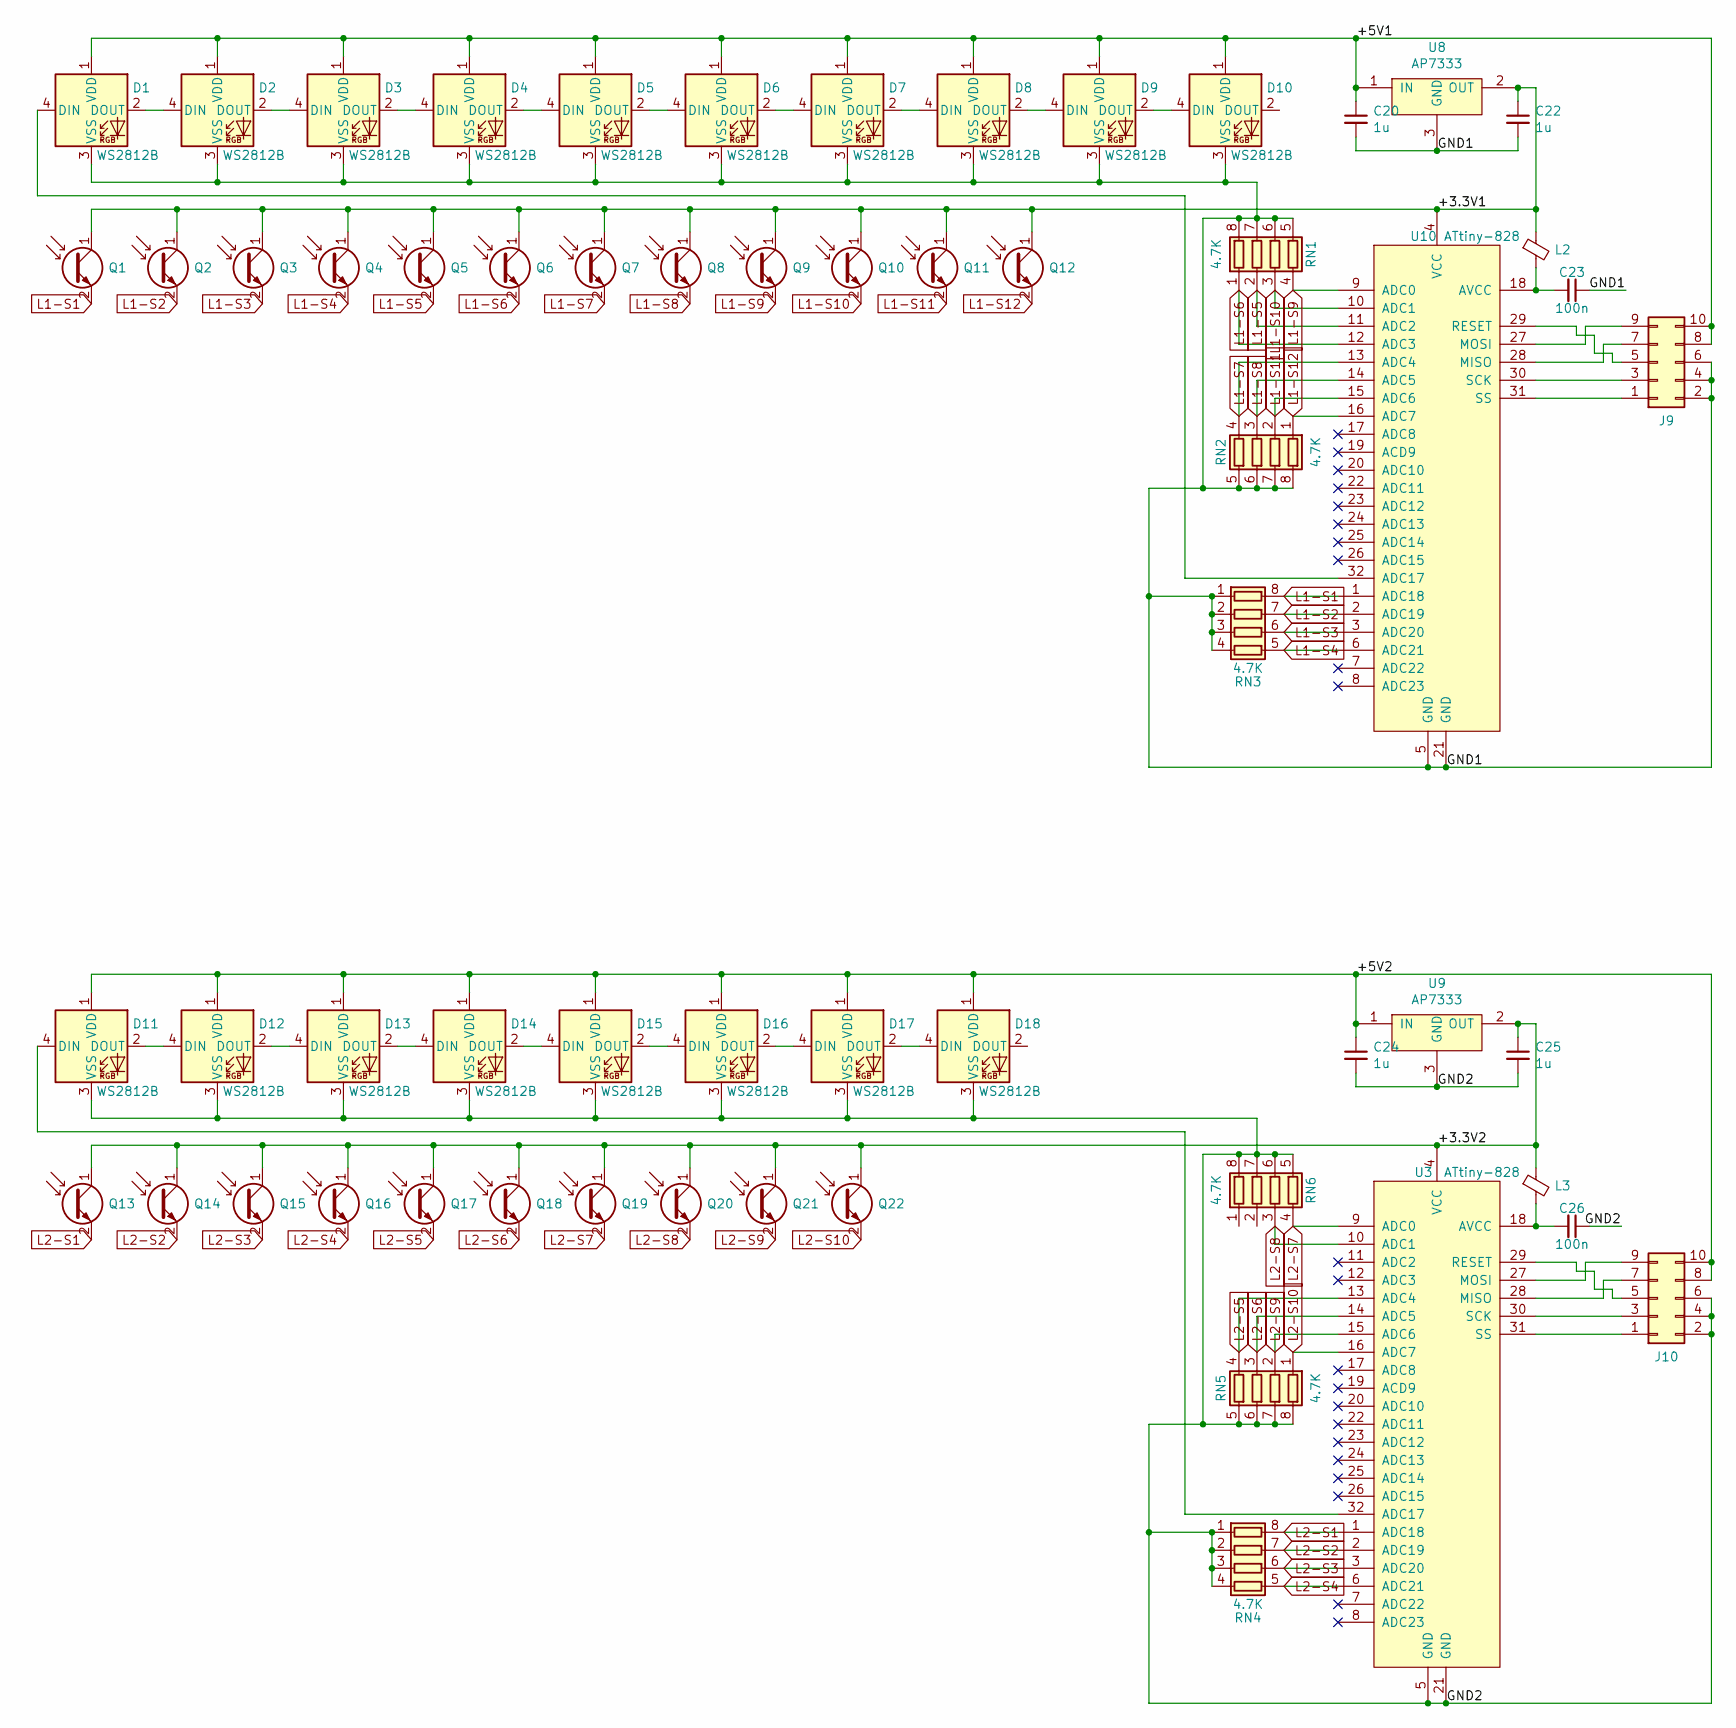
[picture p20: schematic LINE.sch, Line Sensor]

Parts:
C20, C22, C24, C25: 1u; 2012
C23, C26: 100n; 1005
D1, D2, D3, D4, D5, D6, D7, D8, D9, D10, D11, D12, D13, D14, D15, D16, D17, D18: WS2812B
J9, J10: Conn_02x05_Odd_Even; CONN_SPRING_02x05; Part # A120577CT-ND
L2, L3: Ferrite_Bead_Small; 1608
Q1, Q2, Q3, Q4, Q6, Q7, Q8, Q9, Q10, Q11, Q12, Q13, Q14, Q15, Q16, Q17, Q18, Q19, Q20, Q21, Q22: Q_Photo_NPN; PS1101W; Part # PS1101W
Q5: Q_Photo_NPN; PS1101W; PArt # PS1101W
RN1, RN2, RN3, RN4, RN5, RN6: 4.7K; 4RES_ARRAY_SMALL; Part # EXB-28V472JX
U3, U10: ATtiny-828; VQFN-32-5x5mm_P0.5mm
U8, U9: AP7333; Q_SOT-23

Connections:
/+3.3V1: C22.1, L2.1, Q1.1 (C), Q2.1 (C), Q3.1 (C), Q4.1 (C), Q5.1 (C), Q6.1 (C), Q7.1 (C), Q8.1 (C), Q9.1 (C), Q10.1 (C), Q11.1 (C), Q12.1 (C), U8.2 (OUT), U10.4 (VCC)
/+3.3V2: C25.1, L3.1, Q13.1 (C), Q14.1 (C), Q15.1 (C), Q16.1 (C), Q17.1 (C), Q18.1 (C), Q19.1 (C), Q20.1 (C), Q21.1 (C), Q22.1 (C), U3.4 (VCC), U9.2 (OUT)
/+5V1: C20.1, D1.1 (VDD), D2.1 (VDD), D3.1 (VDD), D4.1 (VDD), D5.1 (VDD), D6.1 (VDD), D7.1 (VDD), D8.1 (VDD), D9.1 (VDD), D10.1 (VDD), J9.8, J9.10, U8.1 (IN)
/+5V2: C24.1, D11.1 (VDD), D12.1 (VDD), D13.1 (VDD), D14.1 (VDD), D15.1 (VDD), D16.1 (VDD), D17.1 (VDD), D18.1 (VDD), J10.8, J10.10, U9.1 (IN)
/GND1: C20.2, C22.2, C23.1, D1.3 (VSS), D2.3 (VSS), D3.3 (VSS), D4.3 (VSS), D5.3 (VSS), D6.3 (VSS), D7.3 (VSS), D8.3 (VSS), D9.3 (VSS), D10.3 (VSS), J9.2, J9.4, J9.6, RN1.5 (R4.2), RN1.6 (R3.2), RN1.7 (R2.2), RN1.8 (R1.2), RN2.5 (R4.2), RN2.6 (R3.2), RN2.7 (R2.2), RN2.8 (R1.2), RN3.1 (R1.1), RN3.2 (R2.1), RN3.3 (R3.1), RN3.4 (R4.1), U8.3 (GND), U10.5 (GND), U10.21 (GND)
/GND2: C24.2, C25.2, C26.1, D11.3 (VSS), D12.3 (VSS), D13.3 (VSS), D14.3 (VSS), D15.3 (VSS), D16.3 (VSS), D17.3 (VSS), D18.3 (VSS), J10.2, J10.4, J10.6, RN4.1 (R1.1), RN4.2 (R2.1), RN4.3 (R3.1), RN4.4 (R4.1), RN5.5 (R4.2), RN5.6 (R3.2), RN5.7 (R2.2), RN5.8 (R1.2), RN6.5 (R4.2), RN6.6 (R3.2), RN6.7 (R2.2), RN6.8 (R1.2), U3.5 (GND), U3.21 (GND), U9.3 (GND)
L1-S1: Q1.2 (E), RN3.8 (R1.2), U10.1 (ADC18)
L1-S2: Q2.2 (E), RN3.7 (R2.2), U10.2 (ADC19)
L1-S3: Q3.2 (E), RN3.6 (R3.2), U10.3 (ADC20)
L1-S4: Q4.2 (E), RN3.5 (R4.2), U10.6 (ADC21)
L1-S5: Q5.2 (E), RN1.2 (R2.1), U10.11 (ADC2)
L1-S6: Q6.2 (E), RN1.1 (R1.1), U10.12 (ADC3)
L1-S7: Q7.2 (E), RN2.4 (R4.1), U10.13 (ADC4)
L1-S8: Q8.2 (E), RN2.3 (R3.1), U10.14 (ADC5)
L1-S9: Q9.2 (E), RN1.4 (R4.1), U10.9 (ADC0)
L1-S10: Q10.2 (E), RN1.3 (R3.1), U10.10 (ADC1)
L1-S11: Q11.2 (E), RN2.2 (R2.1), U10.15 (ADC6)
L1-S12: Q12.2 (E), RN2.1 (R1.1), U10.16 (ADC7)
L2-S1: Q13.2 (E), RN4.8 (R1.2), U3.1 (ADC18)
L2-S2: Q14.2 (E), RN4.7 (R2.2), U3.2 (ADC19)
L2-S3: Q15.2 (E), RN4.6 (R3.2), U3.3 (ADC20)
L2-S4: Q16.2 (E), RN4.5 (R4.2), U3.6 (ADC21)
L2-S5: Q17.2 (E), RN5.4 (R4.1), U3.13 (ADC4)
L2-S6: Q18.2 (E), RN5.3 (R3.1), U3.14 (ADC5)
L2-S7: Q19.2 (E), RN6.4 (R4.1), U3.9 (ADC0)
L2-S8: Q20.2 (E), RN6.3 (R3.1), U3.10 (ADC1)
L2-S9: Q21.2 (E), RN5.2 (R2.1), U3.15 (ADC6)
L2-S10: Q22.2 (E), RN5.1 (R1.1), U3.16 (ADC7)
unnamed: C23.2, L2.2, U10.18 (AVCC)
unnamed: C26.2, L3.2, U3.18 (AVCC)
unnamed: D1.2 (DOUT), D2.4 (DIN)
unnamed: D1.4 (DIN), U10.32 (ADC17)
unnamed: D2.2 (DOUT), D3.4 (DIN)
unnamed: D3.2 (DOUT), D4.4 (DIN)
unnamed: D4.2 (DOUT), D5.4 (DIN)
unnamed: D5.2 (DOUT), D6.4 (DIN)
unnamed: D6.2 (DOUT), D7.4 (DIN)
unnamed: D7.2 (DOUT), D8.4 (DIN)
unnamed: D8.2 (DOUT), D9.4 (DIN)
unnamed: D9.2 (DOUT), D10.4 (DIN)
unnamed: D11.2 (DOUT), D12.4 (DIN)
unnamed: D11.4 (DIN), U3.32 (ADC17)
unnamed: D12.2 (DOUT), D13.4 (DIN)
unnamed: D13.2 (DOUT), D14.4 (DIN)
unnamed: D14.2 (DOUT), D15.4 (DIN)
unnamed: D15.2 (DOUT), D16.4 (DIN)
unnamed: D16.2 (DOUT), D17.4 (DIN)
unnamed: D17.2 (DOUT), D18.4 (DIN)
unnamed: J9.1, U10.31 (SS)
unnamed: J9.3, U10.30 (SCK)
unnamed: J9.5, U10.29 (RESET)
unnamed: J9.7, U10.28 (MISO)
unnamed: J9.9, U10.27 (MOSI)
unnamed: J10.1, U3.31 (SS)
unnamed: J10.3, U3.30 (SCK)
unnamed: J10.5, U3.29 (RESET)
unnamed: J10.7, U3.28 (MISO)
unnamed: J10.9, U3.27 (MOSI)

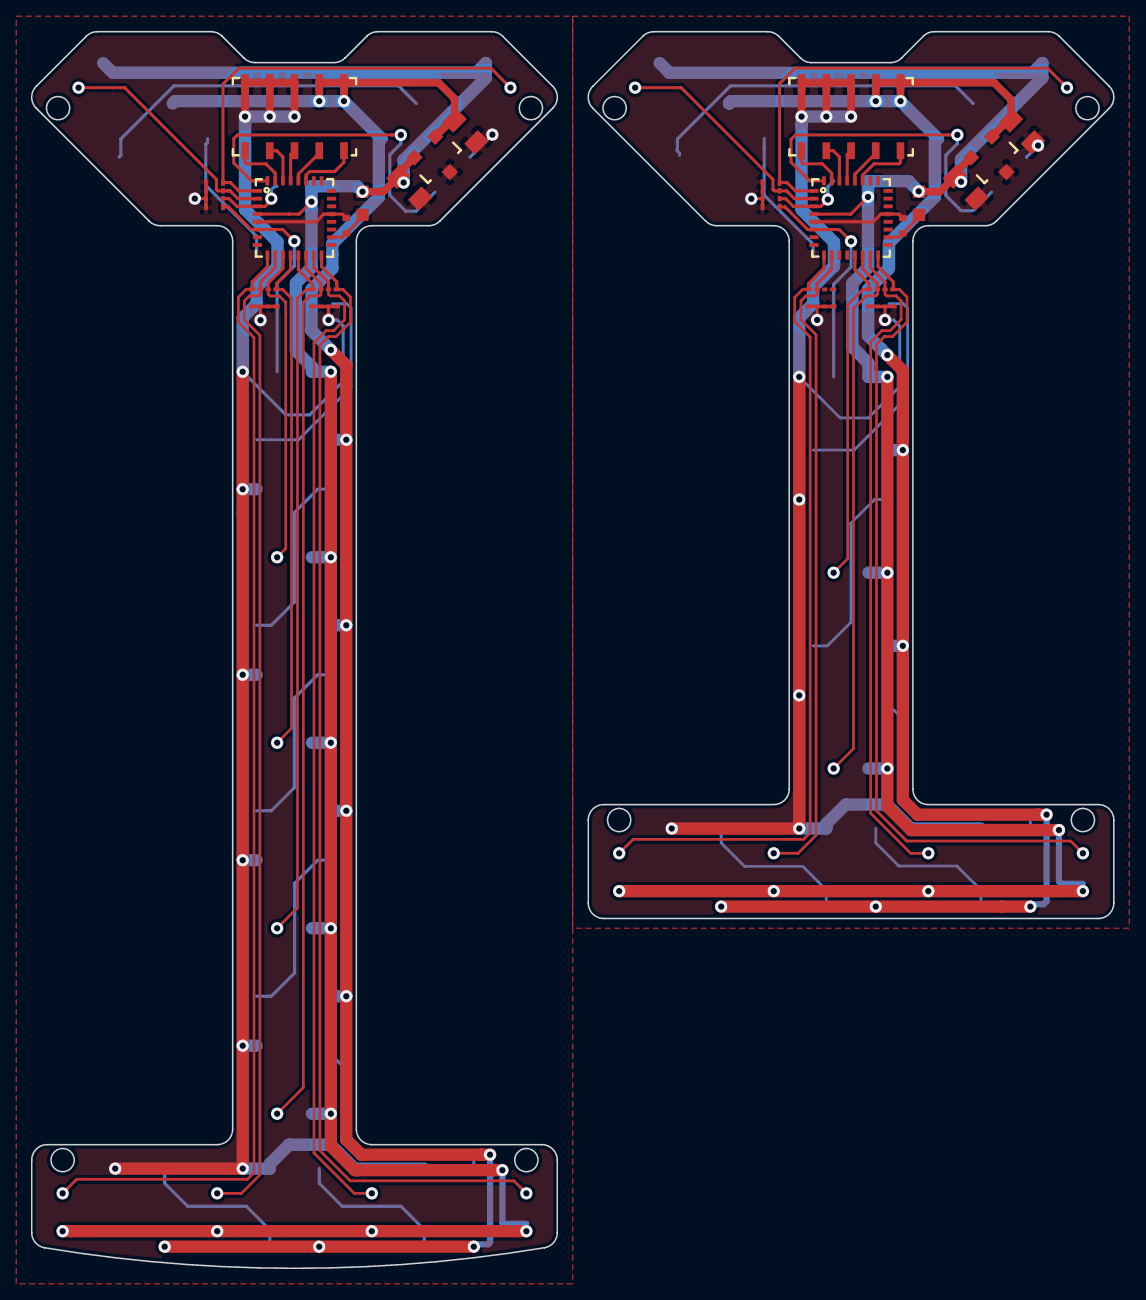
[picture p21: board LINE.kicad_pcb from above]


Board: 2 copper layers, 70.0 x 80.0 mm, 60 parts (40 on the bottom side), 58 nets.

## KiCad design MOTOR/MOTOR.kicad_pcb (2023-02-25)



Board: 2 copper layers, 60.0 x 60.0 mm, 69 parts (20 on the bottom side), 67 nets.

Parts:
C4: CP; CP_φ6.3
C5, C7, C8, C11, C17, C19, C21, C29: 0.1u; 1005
C6, C9, C18, C27: 1uF_16v; 1005
C10, C12, C28, C30: 10u; CAPACITOR_Φ5
C13, C14, C15, C16, C31, C32, C33, C34: 1uF_6.3v; 1005
J1: Conn_01x09; CONN_01x09
J2: KICKER_L; CONN_01x03
J3: KICKER_R; CONN_01x03
J4: MC; Molex_2pin_angled
J5: MA; Molex_2pin_angled
J6: MD; Molex_2pin_angled
J7: MB; Molex_2pin_angled
J8: Conn_01x02; 2Pads
J11: Conn_01x02; XT30
Q23, Q24, Q25, Q26, Q27, Q28, Q29, Q30, Q31, Q32, Q33, Q34, Q35, Q36, Q37, Q38: MOS; 8-PQFN_3x3
R1, R13, R14, R15, R16, R23, R24, R25, R26: 10K; 1005
R2, R3: 100R; 1005
R17, R18, R27, R28: 68K; 1005
U1, U2, U4, U5: DRV8701E; DRV8701

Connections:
GND: C4.2, C7.2, C10.2, C11.2, C12.2, C13.2, C14.2, C15.2, C16.2, C19.2, C28.2, C29.2, C30.2, C31.2, C32.2, C33.2, C34.2, J1.1, J2.2, J3.2, J8.2, J11.2, Q25.3, Q26.3, Q27.3, Q28.3, Q33.3, Q34.3, Q35.3, Q36.3, R1.2, U1.5, U1.16, U1.20, U1.21, U1.25, U2.5, U2.16, U2.20, U2.21, U2.25, U4.5, U4.16, U4.20, U4.21, U4.25, U5.5, U5.16, U5.20, U5.21, U5.25
KICKER_L: J1.3, R2.1
KICKER_R: J1.7, R3.2
MOTOR_RESET: J1.5, R1.1, U1.13, U2.13, U4.13, U5.13
MVDD: C4.1, C6.1, C7.1, C9.1, C10.1, C11.1, C12.1, C18.1, C19.1, C27.1, C28.1, C29.1, C30.1, J1.9, J2.1, J3.1, J8.1, J11.1, Q23.2, Q24.2, Q29.2, Q30.2, Q31.2, Q32.2, Q37.2, Q38.2, U1.1, U2.1, U4.1, U5.1
unnamed: C5.1, U1.3
unnamed: C5.2, U1.4
unnamed: C6.2, U1.2
unnamed: C8.1, U2.3
unnamed: C8.2, U2.4
unnamed: C9.2, U2.2
unnamed: C13.1, R17.2, U1.6, U1.7
unnamed: C14.1, R18.2, U2.6, U2.7
unnamed: C15.1, R13.2, R15.2, U1.8, U1.14
unnamed: C16.1, R14.2, R16.2, U2.8, U2.14
unnamed: C17.1, U4.3
unnamed: C17.2, U4.4
unnamed: C18.2, U4.2
unnamed: C21.1, U5.3
unnamed: C21.2, U5.4
unnamed: C27.2, U5.2
unnamed: C31.1, R27.2, U4.6, U4.7
unnamed: C32.1, R28.2, U5.6, U5.7
unnamed: C33.1, R23.2, R25.2, U4.8, U4.14
unnamed: C34.1, R24.2, R26.2, U5.8, U5.14
unnamed: J2.3, R2.2
unnamed: J3.3, R3.1
unnamed: J4.1, Q23.3, Q25.2, U1.23
unnamed: J4.2, Q27.2, Q29.3, U1.18
unnamed: J5.1, Q24.3, Q26.2, U2.23
unnamed: J5.2, Q28.2, Q30.3, U2.18
unnamed: J6.1, Q31.3, Q33.2, U4.23
unnamed: J6.2, Q35.2, Q37.3, U4.18
unnamed: J7.1, Q32.3, Q34.2, U5.23
unnamed: J7.2, Q36.2, Q38.3, U5.18
unnamed: Q23.1, U1.24
unnamed: Q24.1, U2.24
unnamed: Q25.1, U1.22
unnamed: Q26.1, U2.22
unnamed: Q27.1, U1.19
unnamed: Q28.1, U2.19
unnamed: Q29.1, U1.17
unnamed: Q30.1, U2.17
unnamed: Q31.1, U4.24
unnamed: Q32.1, U5.24
unnamed: Q33.1, U4.22
unnamed: Q34.1, U5.22
unnamed: Q35.1, U4.19
unnamed: Q36.1, U5.19
unnamed: Q37.1, U4.17
unnamed: Q38.1, U5.17
unnamed: R13.1, U1.9
unnamed: R14.1, U2.9
unnamed: R15.1, U1.10
unnamed: R16.1, U2.10
unnamed: R17.1, U1.12
unnamed: R18.1, U2.12
unnamed: R23.1, U4.9
unnamed: R24.1, U5.9
unnamed: R25.1, U4.10
unnamed: R26.1, U5.10
unnamed: R27.1, U4.12
unnamed: R28.1, U5.12
PWM_A: J1.8, U2.15
PWM_B: J1.6, U5.15
PWM_C: J1.4, U1.15
PWM_D: J1.2, U4.15

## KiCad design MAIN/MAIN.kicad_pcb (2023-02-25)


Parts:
C1, C2, C13, C14: 1u; 2012
C3: 1u; 1005
C4, C5, C9, C10, C11, C12, C15, C16, C17, C18, C19, C21: 100n; 1005
C6: 4.7uF; 1005
C7, C8: 4.3pF; 1005
C29: 22u; 2012
C30: 10u; 2012
C31: 47u; CAPACITOR_φ6.3
D19, D22: RED; 1608
D20, D24: GREEN; 1608
D21, D25: D; DO-214AC
D23: WHITE; 1608
DC1: Murata_DC-DC; Murata_DCDC; Part # OKL-T/6-W12N-C
J1: GYRO; CONN_01x04; Part # FSS-41035-04
J4: To-Motor; CONN_01x09; Part # PSS-410153-09
J6: USB_B_Mini; USB_MINIB_SMDandTHT
J7: To-Top; IDC_Header_Straight_26pins_P1.27mm; Part # 3220-26-0100-00
J8: To-Bottom; IDC_Header_Straight_26pins_P1.27mm; Part # 3220-26-0100-00
J12, J13: SWD; Writing_STM
J14: Test Port; PH-ST02
J15: SP; 2Pads
L1: Ferrite_Bead_Small; 1608
Q23: Q_NMOS_GSD; Q_SOT-23; Part # SSM3K357R,LF
R1, R7, R8, R17, R27, R28, R29, R30: 10K; 1005
R2, R15, R16, R18, R19, R23: 1K; 1005
R3: 20K; 1005
R4, R5, R9: 100K; 1005
R6: 1K5; 1005
R10, R11: 4K7; 1005
R12, R13, R14, R25: 100R; 1005
R20, R21: 4.7K; 1005
R22: 1.2K; 1005
R24: 330R; 1005
R26: 47K; 1005
SW1: START; Tact_Switch-4.5x4.5
SW2: RESET; Tact_Switch-4.5x4.5
U1, U6: AP7333; Q_SOT-23
U2: TWE_LITE_SMD; smd_TOCOS
U4: STM32F446RETx; LQFP-64_10x10mm_P0.5mm
U5: STM32F103CBTx; TQFP-48_7x7mm_P0.5mm
U7: M24C64-RDW6TP; TSSOP-8_4.4x3mm_P0.65mm; Part # M24C64-RDW6TP
Y1, Y3: 8MHz; CERALOCK
Y2: 32.768kHz; CRYSTAL_FC135

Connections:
+3V3: C3.1, C9.1, C10.1, C11.1, C12.1, C14.1, J1.1, L1.1, R18.1, R20.1, R21.1, R28.2, R30.2, U2.5 (VCC), U4.1 (VBAT), U4.19 (VDD), U4.32 (VDD), U4.48 (VDD), U4.64 (VDD), U6.2 (OUT), U7.8 (VCC)
+3V3_2: C2.1, C16.1, C17.1, C18.1, C19.1, D20.2 (A), R4.1, R6.1, R10.1, U1.2 (OUT), U5.1 (VBAT), U5.9 (VDDA), U5.24 (VDD), U5.36 (VDD), U5.48 (VDD)
+5V: C13.1, C30.1, C31.1, D21.1 (K), DC1.4 (Vout), DC1.5 (Sense), J7.25, J7.26, J8.1, J8.2, J14.1, J15.1, R22.1, U6.1 (IN)
+12V: D25.2 (A), J4.9, R26.1
/CS: J7.7, U4.42 (PA9)
/DC: J7.9, U4.39 (PC8)
/HOLD1: J8.15, U4.24 (PC4)
/HOLD2: J8.22, U4.10 (PC2)
/KICKER_L: J4.3, U4.57 (PB5)
/KICKER_R: J4.7, U4.58 (PB6)
/LED_STLINK: R12.2, R13.2, U5.30 (PA9)
/MISO: J7.22, J8.5, U4.22 (PA6)
/MONO_RX: U2.9 (RX), U4.51 (PC10)
/MONO_TX: U2.8 (TX), U4.52 (PC11)
/MOSI: J7.20, J8.7, R2.1
/MOTOR_RESET: J4.5, U4.61 (PB8)
/MV_RX: J7.13, U4.37 (PC6)
/MV_TX: J7.11, U4.38 (PC7)
/NRST: C21.2, R28.1, R29.2, SW2.4, U4.7 (NRST)
/PWM_A: J4.8, U4.56 (PB4)
/PWM_B: J4.6, U4.62 (PB9)
/PWM_C: J4.4, U4.59 (PB7)
/PWM_D: J4.2, U4.55 (PB3)
/PWM_DB: J7.17, U4.35 (PB14)
/PWM_DF: J7.15, U4.36 (PB15)
/RST_LINE1: J8.18, U4.14 (PA0)
/RST_LINE2: J8.17, U4.25 (PC5)
/RST_LINE3: J8.24, U4.9 (PC1)
/RST_LINE4: J8.21, U4.27 (PB1)
/RST_SONIC: J7.10, U4.29 (PB10)
/SCK: J7.18, J8.9, U4.21 (PA5)
/SCL: J1.3, J7.16, J8.11, R20.2, U4.41 (PA8), U7.6 (SCL)
/SDA: J1.4, J7.14, J8.13, R21.2, U4.40 (PC9), U7.5 (SDA)
/SPEAKER: Q23.1 (G), R19.2, U4.54 (PD2)
/SS_LINE1: J8.16, U4.15 (PA1)
/SS_LINE2: J8.20, U4.11 (PC3)
/SS_LINE3: J8.26, U4.2 (PC13)
/SS_LINE4: J8.19, U4.26 (PB0)
/SS_MOUSE: J8.14, U4.20 (PA4)
/SS_SONIC: J7.8, U4.28 (PB2)
/START: J7.19, R17.1, SW1.3, U4.34 (PB13)
/STM_JTCK: J13.2, U5.37 (PA14)
/STM_JTMS: J13.3, U5.34 (PA13)
/SWC: J12.2, U4.49 (PA14), U5.26 (PB13)
/SWD: J12.3, R14.2, U4.46 (PA13), U5.27 (PB14)
/TAPTIC: J7.12, U4.33 (PB12)
/USART_RX: U4.17 (PA3), U5.12 (PA2)
/USART_TX: U4.16 (PA2), U5.13 (PA3)
/USB_DM: J6.2 (D-), J7.4, U5.32 (PA11)
/USB_DP: J6.3 (D+), J7.5, R6.2, U5.33 (PA12)
GND: C1.2, C2.2, C3.2, C4.1, C5.2, C6.2, C7.2, C8.2, C9.2, C10.2, C11.2, C12.2, C13.2, C14.2, C15.2, C16.2, C17.2, C18.2, C19.2, C21.1, C29.2, C30.2, C31.2, D19.1 (K), D22.1 (K), D23.1 (K), D24.1 (K), DC1.1 (ON/OFF), DC1.3 (GND), DC1.7 (GND), J1.2, J4.1, J6.5 (GND), J6.6 (Shield), J7.3, J7.6, J7.21, J7.23, J7.24, J8.3, J8.4, J8.6, J8.8, J8.10, J8.12, J8.23, J8.25, J12.1, J13.1, J14.2, Q23.2 (S), R1.2, R3.2, R5.2, R7.2, R8.2, R9.2, R11.1, R17.2, R19.1, R22.2, R25.2, R27.2, SW2.1, SW2.2, SW2.5, U1.3 (GND), U2.20 (GND), U2.28 (GND), U2.30 (GND), U2.31 (GND), U2.32 (GND), U4.12 (VSSA), U4.18 (VSS), U4.31 (VSS), U4.47 (VSS), U4.63 (VSS), U5.8 (VSSA), U5.23 (VSS), U5.35 (VSS), U5.47 (VSS), U6.3 (GND), U7.2 (A1), U7.3 (A2), U7.4 (GND), Y1.2, Y3.2
unnamed: C4.2, L1.2, U4.13 (VDDA)
unnamed: C5.1, R29.1, U5.18 (PB0)
unnamed: C6.1, U4.30 (VCAP_1)
unnamed: C7.1, U4.3 (PC14), Y2.1
unnamed: C8.1, U4.4 (PC15), Y2.2
unnamed: C15.1, R4.2, U5.7 (NRST)
unnamed: C29.1, D25.1 (K), DC1.2 (Vin), R3.1
unnamed: D19.2 (A), R12.1
unnamed: D20.1 (K), R13.1
unnamed: D22.2 (A), R15.2
unnamed: D23.2 (A), R16.2
unnamed: D24.2 (A), R18.2
unnamed: DC1.6 (Trim), R23.1
unnamed: J6.4 (ID), R9.1
unnamed: J15.2, Q23.3 (D)
unnamed: R1.1, U4.60 (BOOT0)
unnamed: R2.2, U4.23 (PA7)
unnamed: R5.1, U5.44 (BOOT0)
unnamed: R7.1, U5.2 (PC13)
unnamed: R8.1, U5.3 (PC14)
unnamed: R10.2, R11.2, U5.10 (PA0)
unnamed: R14.1, U5.25 (PB12)
unnamed: R15.1, U4.44 (PA11)
unnamed: R16.1, U4.43 (PA10)
unnamed: R23.2, R24.1
unnamed: R24.2, R25.1
unnamed: R26.2, R27.1, U4.8 (PC0)
unnamed: R30.1, SW1.2, SW1.5
unnamed: U4.5 (PH0), Y1.1
unnamed: U4.6 (PH1), Y1.3
unnamed: U5.5 (PD0), Y3.1
unnamed: U5.6 (PD1), Y3.3
UVDD: C1.1, D21.2 (A), J6.1 (VBUS), J7.1, J7.2, U1.1 (IN)



Board: 2 copper layers, 60.0 x 60.0 mm, 83 parts (23 on the bottom side), 84 nets.
